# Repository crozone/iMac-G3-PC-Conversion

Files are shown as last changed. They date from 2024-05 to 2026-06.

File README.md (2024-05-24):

# iMac G3 - Gaming PC Conversion

Parts and instructions to convert an iMac G3 into a powerful, modern gaming PC.

* AMD Ryzen 5900X
* 32GB 3600 RAM
* ASUS ROG Strix X570-I
* NVIDIA 3080 (ASUS TUF OC)
* 750W Corsair PSU
* Custom water loop with D5 pump and 200x200mm radiator

## About

This is a project to convert a year ~2000 Apple iMac G3 DV (slot load, Graphite) computer into a fully fledged gaming PC, to serve as a portable LAN box and VR machine.

The donor iMac was broken and completely missing the actual compute unit, so no working iMacs were harmed in the making of this monstrosity.

This concept certainly isn't new, but I'm hoping to set this project apart by reducing the amount of destructive case modifications, and packing in significantly more power, hopefully without melting everything.

The project is still in-progress, but should eventually become an instructional kit for reproducing the mod.

## Project Status

### TODO

* Final laser cut parts for radiator mounting
* Additional brackets for case reinforcements
* Fan shroud to direct air through rear vent
* Additional fan mounts
* Slot loading BD drive bracket
* Case front panel wiring
* Side panel for IO extensions
* Final assembly
* Full documentation of all chassis modifications, third party parts, part locations, and assembly instructions

### What's complete

* All parts mounted in their final locations
* Custom water loop is complete and pressure tested (0.5 bar / 15 mins)
* PSU is patched to 240V plug on case (original location)
* PSU is wired to mobo, GPU, water pump and display
* UV LEDs placed and wired up to 12V RGB motherboard header
* Water loop filled and tested (small leak in QD fitting but otherwise all good)
* First bootup successful. BIOS configured, Windows 10 installed.
* Stress tested with UNIGINE Heaven benchmark, Prime95. Water loop appears to have plenty of thermal capacity, even at ~500W draw from CPU + GPU.

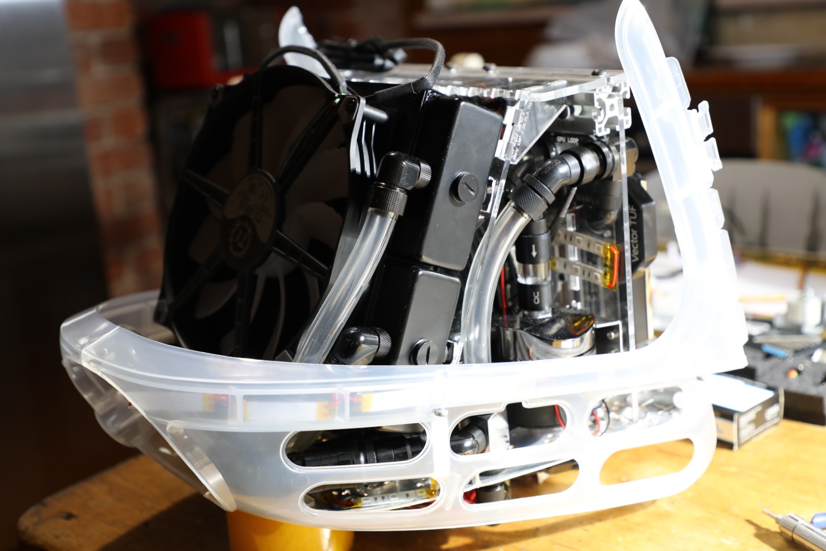
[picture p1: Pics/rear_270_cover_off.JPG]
Rear 270 deg disassembled view


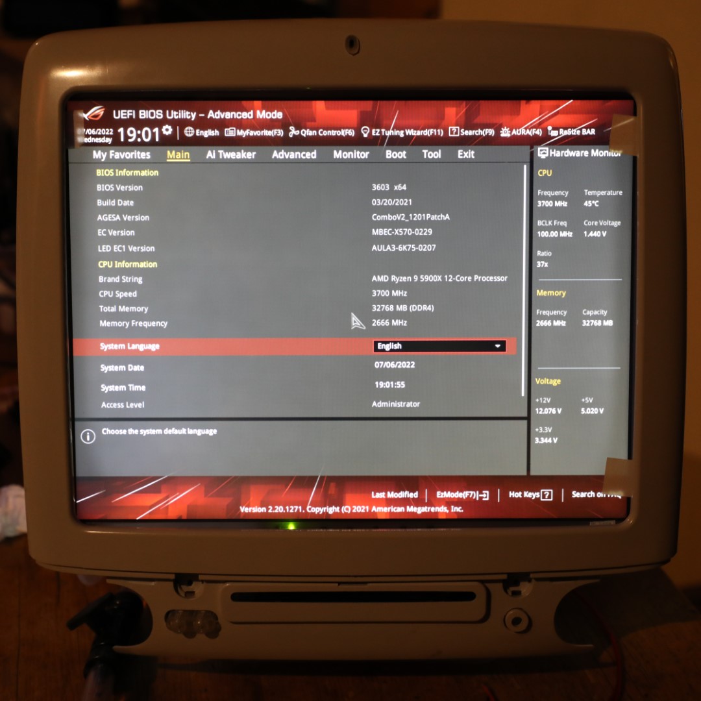
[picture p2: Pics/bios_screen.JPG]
BIOS screen


### Previous similar projects

Recently I discovered another iMac casemod project \([hackaday](https://hackaday.io/project/160719-imac-g3-casemod), [github repo here](https://github.com/Diepzeevogel/iMac-G3-replacement-parts)\). This includes many similar ideas, although the mounting locations are very different. None of the parts are directly usable but provide some good hints for layout.

## Overview of replacement components

### Display

HYDIS HV150UX2-100. It is a 15" LCD LVDS laptop display, that is UXGA (1600x1200), 4:3, and LED backlit. It's a slightly more expensive upgrade to the HV150UX1, which is CCFL backlit. 

The screen is almost a perfect fit for the iMac G3 stock display bezel, except the corners are slightly cut off by the curved edges. However, it's pretty close, and at this size and resolution I have not found a better display for the project, especially since this one has a display controller cheaply available on eBay.

It is held in via 4 3D printed nylon mounting brackets, which fit over the original CRT mounting holes:

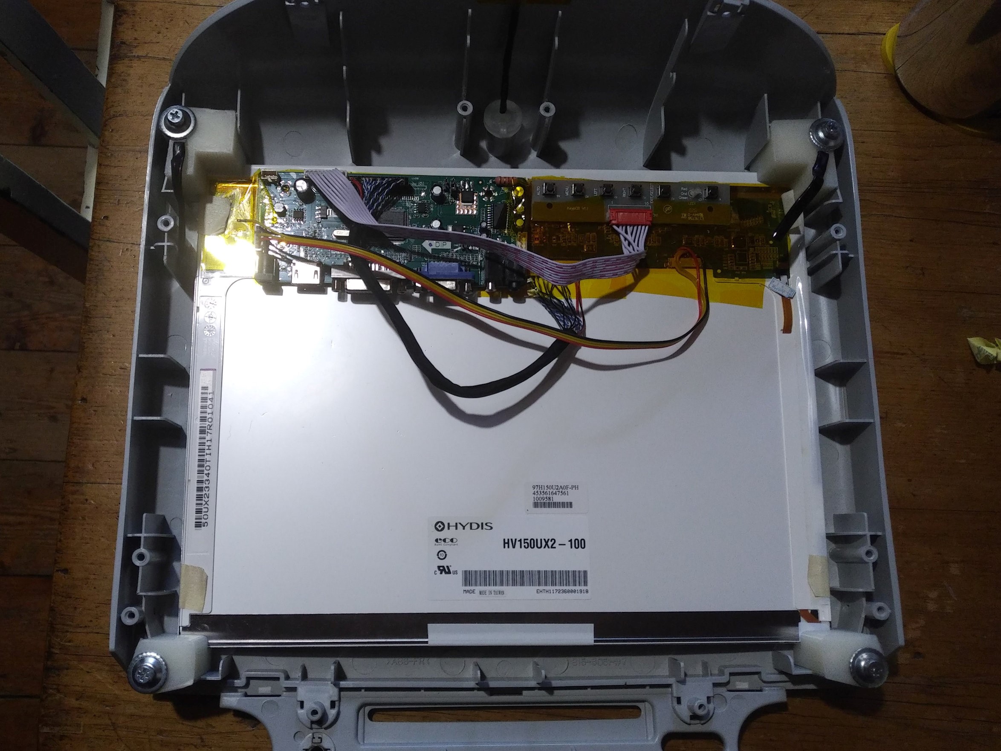
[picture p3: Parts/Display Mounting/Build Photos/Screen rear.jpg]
Display mounted rear


### Display adapter board

The HYDIS display is powered by a M.NT68676.2A.11486 LVDS controller board, which accepts HDMI and 12V power and outputs the display LVDS signal and backlight control.

The M.NT68676.2A.11486 is readily available on eBay as a drop-in controller for the HV150UX1, however it has to be slightly modified to work with the HV150UX2. Mainly, the LVDS connector has to be rewired, and the high voltage backlight driver removed. The power and control wires that previously went to the backlight driver need to be attached to the LCD backlight driver on the HV150UX2 display. Pin 8 of the driver connector also needs to be tied to 5V, to keep the display at maximum brightness, as it appears that the driver board does not set the voltage of this pin correctly.

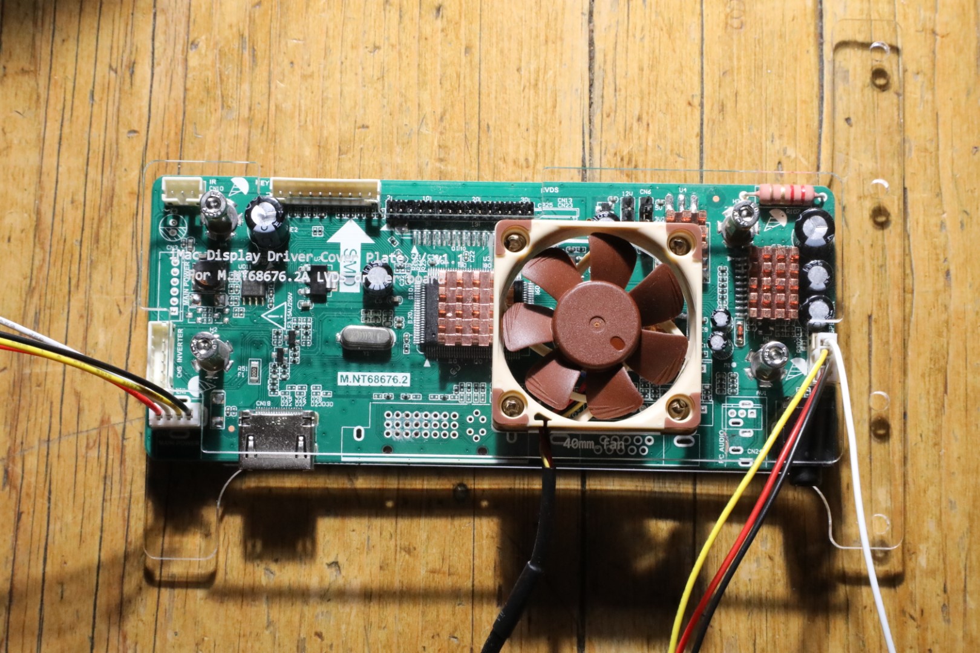
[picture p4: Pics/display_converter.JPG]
Display adapter


### GPU

The GPU is an ASUS 3080 TUF with a EK-Quantum Vector TUF RTX 3080/3090 water block and matching backplate.

It is mounted directly behind the LCD display panel, wedged in-between the LCD and the motherboard. It is mounted to a PCIe riser bracket, which is bolted to the metal chassis baseplate. This allows for a 30cm+ GPU to be mounted across the iMac behind the screen, since it is the widest part of the body. It also leaves more space free towards the rear of the iMac, for a water cooling radiator and PSU.

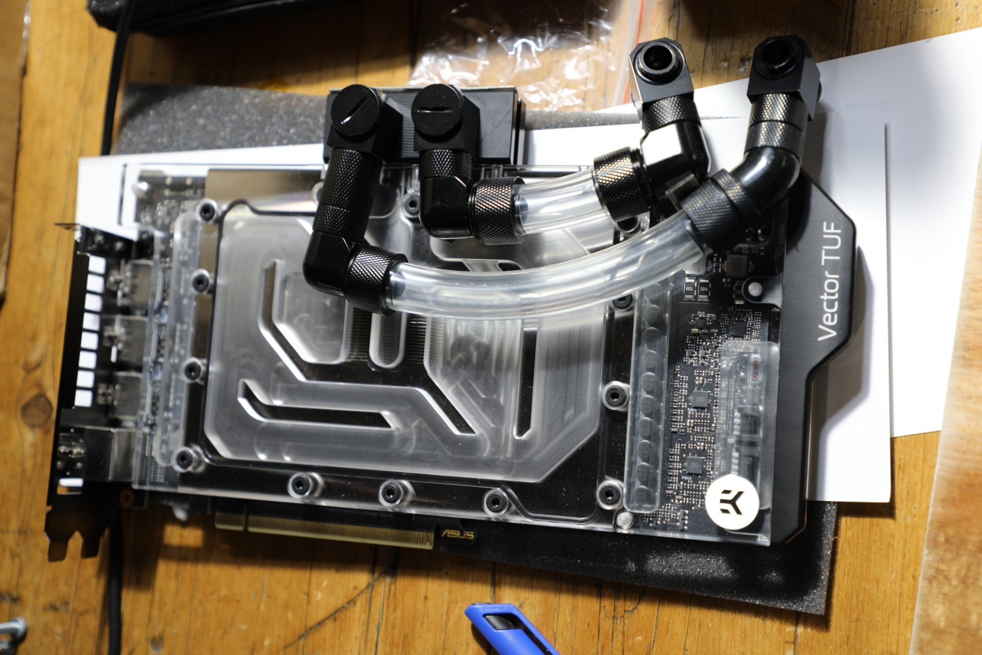
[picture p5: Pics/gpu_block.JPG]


The Koolance low profile right angle fittings (NZL-LXG2) were basically required in order to fit the piping behind the GPU. Thanks Koolance for manufacturing these magical fittings, they came in extremely clutch for this build.

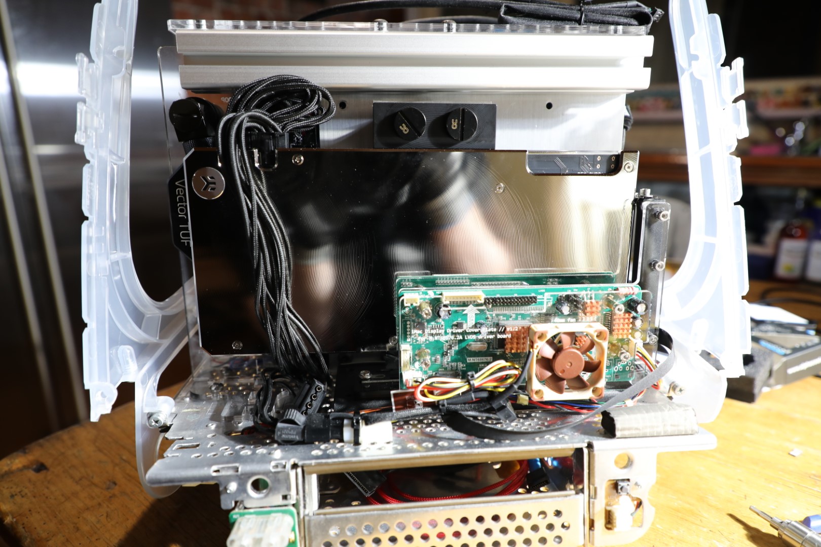
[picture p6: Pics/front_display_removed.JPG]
Display adapter mounted in front of GPU


### Case integration (Speakers, Microphone, Headphone jacks, Power button, Power Lamp)

The [qbancoffee imac_g3_ivad_board_init](https://github.com/qbancoffee/imac_g3_ivad_board_init) project contains a [J22 adapter PCB](https://github.com/qbancoffee/imac_g3_ivad_board_init/tree/master/schematics_and_pcbs/imac_g3_slot_loading_J22_adapter_board) which provides breakouts for the speakers, microphone, headphone jacks, power button, and power lamp. This means that the iMac wiring harnesses does not need to be modified and the original J22 connector can remain in-place.

* The case speakers are powered by a built-in amplifier included on the M.NT68676.2A.11486 display controller, i.e they become the "HDMI Audio" device.

* The microphone is wired into the rear panel mic. The J22 adapter board contains microphone circuitry.

* The power button and lamp are wired to the motherboard through the standard pins

* The headphone jacks are wired into the Front Panel Audio connector. The right jack is wired as a microphone input.

### Drive bay

The original slot-loading DVD drive is being replaced by a Panasonic UJ-265, which is a slot loading BDXL burner. It is a laptop drive that takes a slimline SATA+power cable, which can be easily converted to standard SATA+power with an adapter. It will be mounted with an acrylic bracket to correctly align it with the case slot.

### Motherboard

The motherboard form factor is miniITX. Space is incredibly limited and miniITX is the logical choice. Additionally, good quality microATX motherboards are few and far between, whereas miniITX boards are very popular and well supported.

The motherboard is mounted vertically behind the display using an aluminium backing plate and aluminium extrusion.

### CPU

AMD Ryzen 5900X with EK-Classic CPU water block.

The water block has the stock LEDs removed and replaced with a UV LED strip.

### Side ports

Side ports will need to be extended from the motherboard IO panel and GPU, and onto a 3D printed side panel mounted in the original iMac G3 IO panel location (TODO: Laser Cut Acrylic ports panel)

### PSU

A Corsair 750W SFX form factor PSU is mounted in a laser cut acrylic cage that hangs halfway through the metal baseplate of the iMac case.

The original rear power socket location is retained by reusing the original bracket with a shorter socket, and is extended to the PSU via patch cable.

### Cooling

The iMac G3 was originally designed for passive cooling, which makes active cooling a challenge. There are three main locations where air can be forced into and out of the case: The holes around the carry handle, the meshed access port on the underside, and the holes under the front speakers.

The CPU and GPU are both water cooled with a custom loop.

A large 200mm square radiator ([Alphacool NexXxoS XT45 Full Copper 200mm radiator](https://www.alphacool.com/shop/radiatoren/radiatoren-aktiv/180200-mm/25898/alphacool-nexxxos-xt45-full-copper-200mm-radiator)) and fan sits directly behind the rear carry handle vents.

The pump is a D5 Alphacool VPP655 with an Aquacomputer ULTITOP D5 MIRROR BLACK pump adapter. It is mounted vertically to an acrylic bracket, to the right of the motherboard.

TODO: The underside of the iMac can have smaller 60/70/80mm fans mounted to force air into the case.

### RGB Lights

~~No~~ Only a little RGB in this build... as a treat. Instead it's mostly Ultra-Violet 😎. The water cooling additive is Mayhems X1 concentrate UV green (or maybe red).

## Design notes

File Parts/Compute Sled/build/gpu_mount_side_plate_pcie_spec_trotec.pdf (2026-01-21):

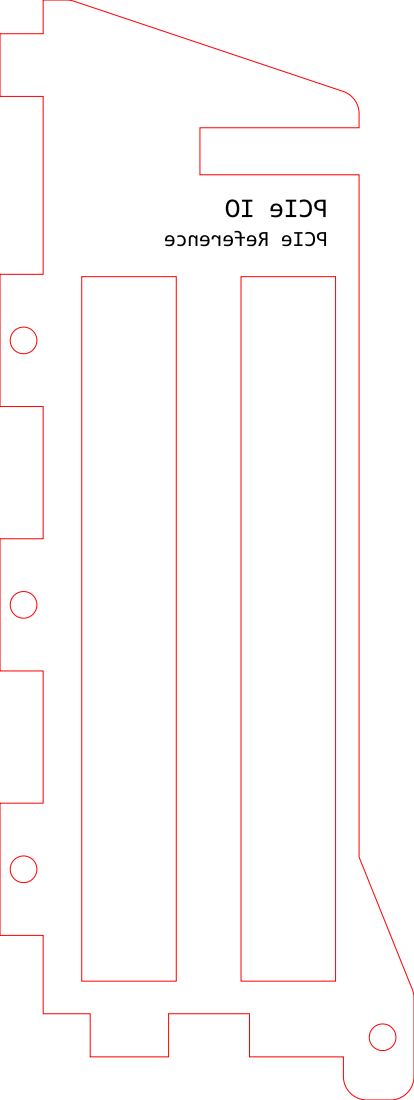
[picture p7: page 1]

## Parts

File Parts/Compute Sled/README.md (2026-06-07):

# Compute Sled

Frame to hold motherboard, water pump, and GPU.

## Fasteners
* 2x 6mm M3 screws [PCIe riser] // TODO CHECK
* 4x 6mm M3 screws [Pump bracket]
* 4x 6mm tall M3 male-female threaded standoffs [Motherboard mounting]
* 2x 6mm M4 screws [GPU card to bracket]
* 6x 12mm M4 screws [GPU bracket mounting]
* 12x 12mm M6 screws [10x for mounting plate brackets, 2x GPU support block]

## PCIe extension

ADT-Link K33UF-TU-FG

PCI-E 5.0 x16 to x16 turn 180 degree splint vertical extension cable

175-180mm length is ideal when used with 6mm thick acrylic.

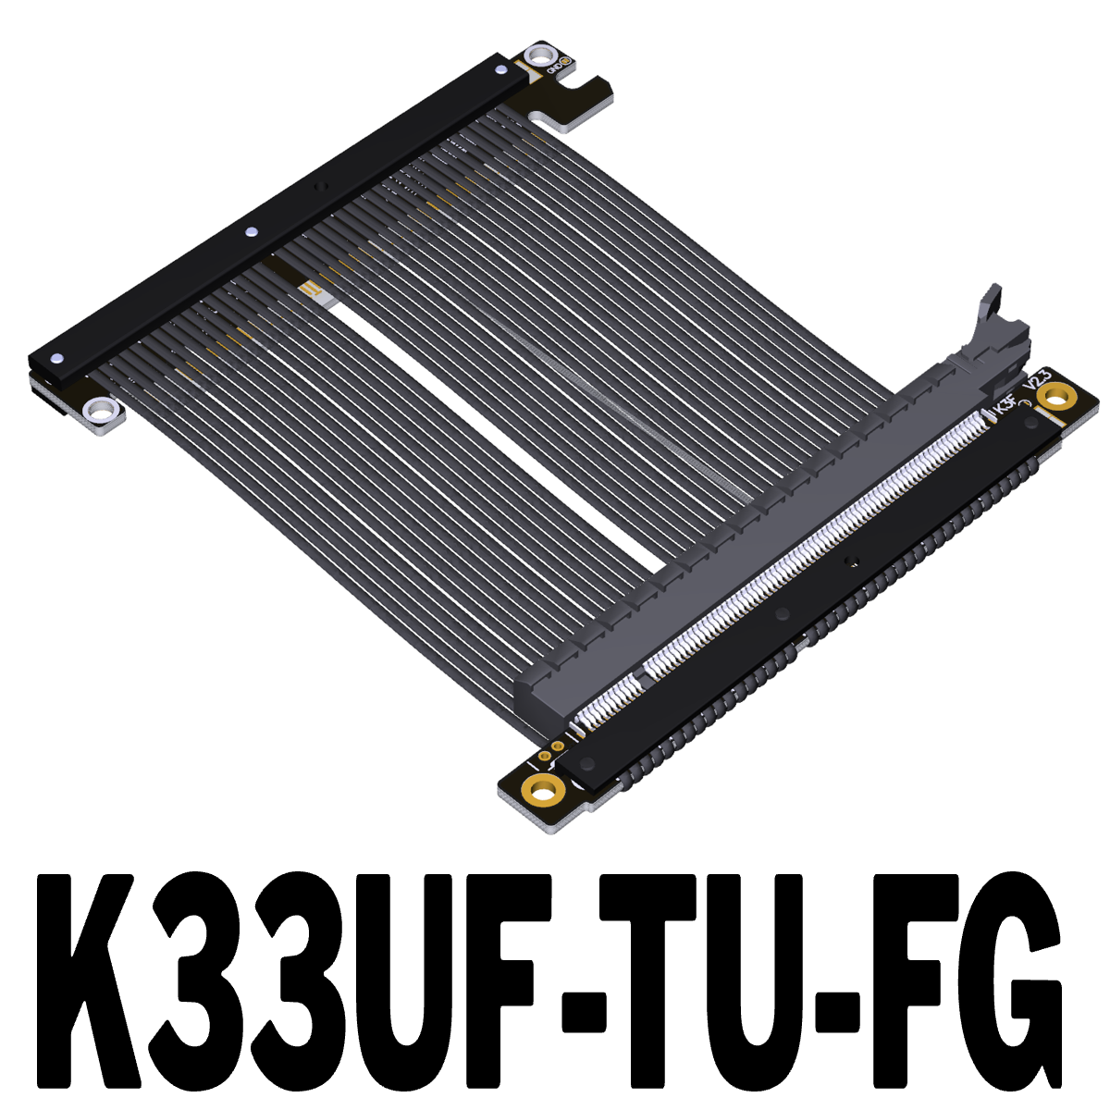
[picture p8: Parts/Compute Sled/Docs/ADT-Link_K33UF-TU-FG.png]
K33UF-TU-FG Render


## Pump

### Pump top with mounting bracket

Aquacomputer ULTITOP D5 MIRROR BLACK pump adapter for D5 pumps, G1/4

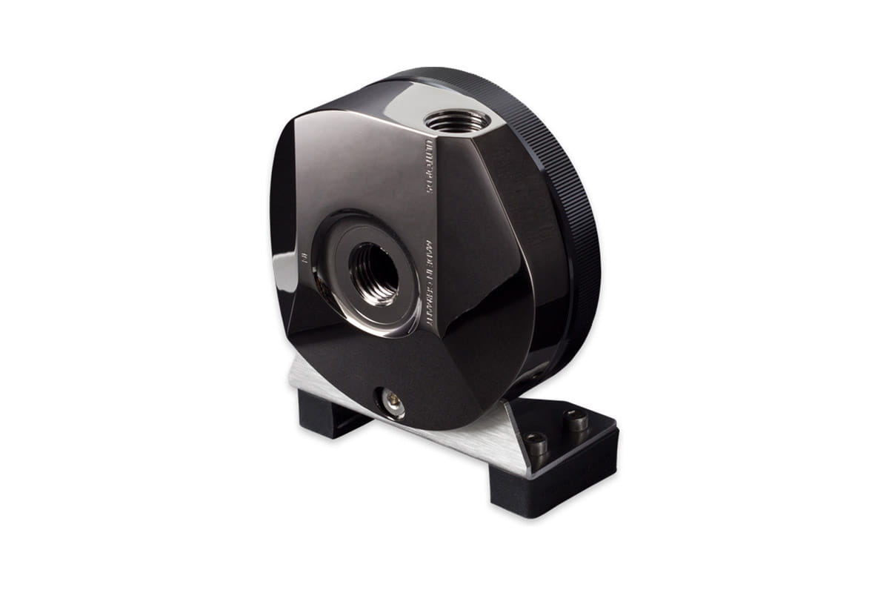
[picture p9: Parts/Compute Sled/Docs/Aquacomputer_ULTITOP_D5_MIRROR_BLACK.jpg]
ULTITOP_D5


### Pump

Alphacool VPP655

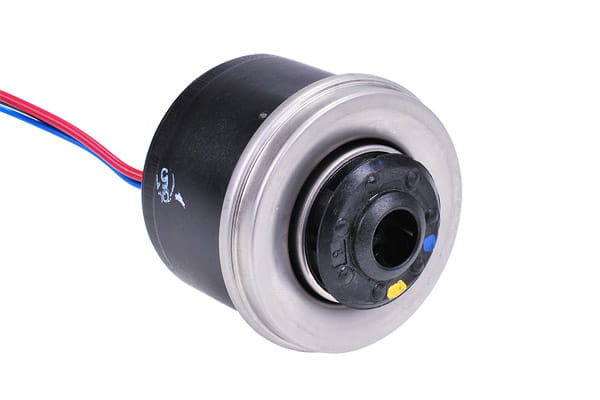
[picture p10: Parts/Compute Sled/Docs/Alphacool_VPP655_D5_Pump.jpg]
Alphacool VPP655


## GPU

Reference GPU is the RTX 5090 TUF with the Alphacool Core GeForce RTX 5090 TUF Gaming GPU Water Block.

Alphacool Core RTX 5090 TUF

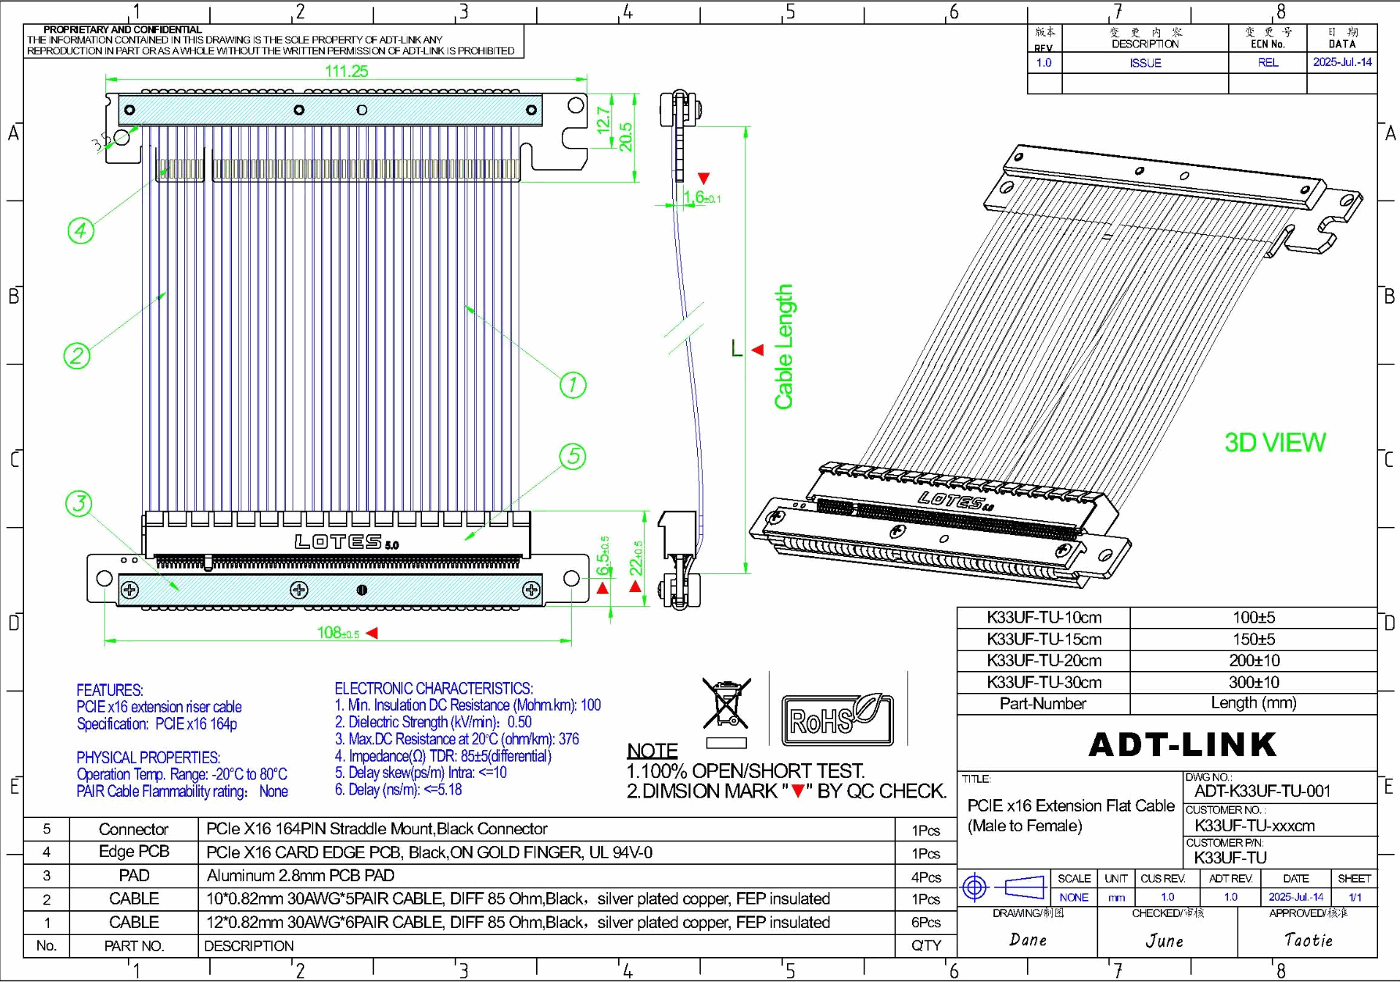
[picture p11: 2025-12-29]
Parts/Compute Sled/Docs/PCIe_riser_K33UF-TU.png

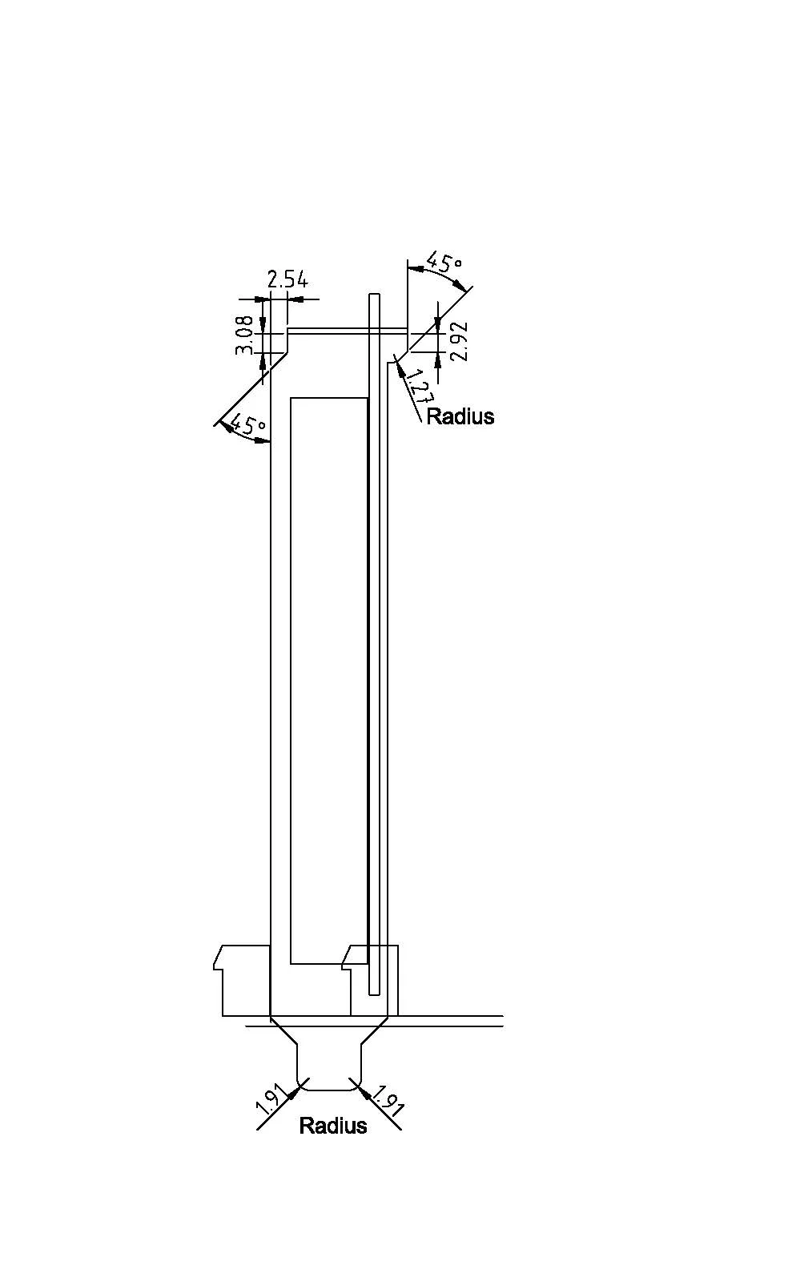
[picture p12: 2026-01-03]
Parts/Compute Sled/Docs/PCIe_Bracket_Face_Drawing_6.jpeg

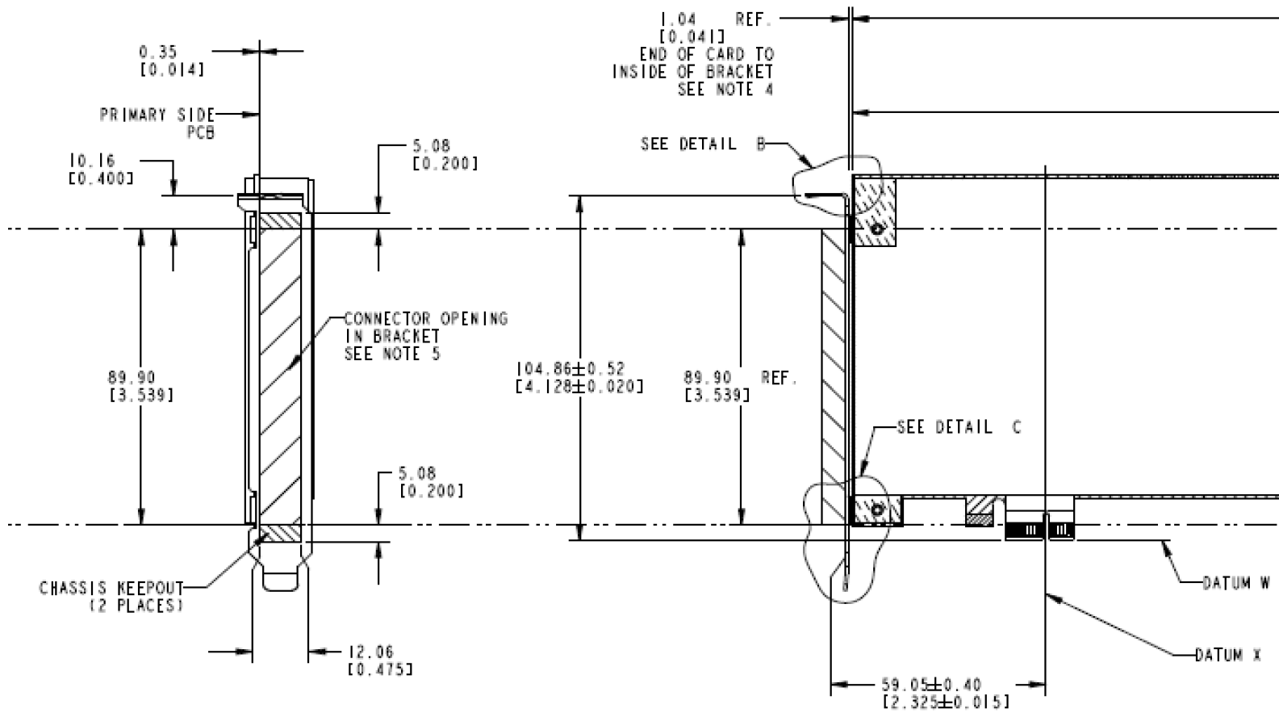
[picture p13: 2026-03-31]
Parts/Compute Sled/Docs/Bracket_drawing_3.png

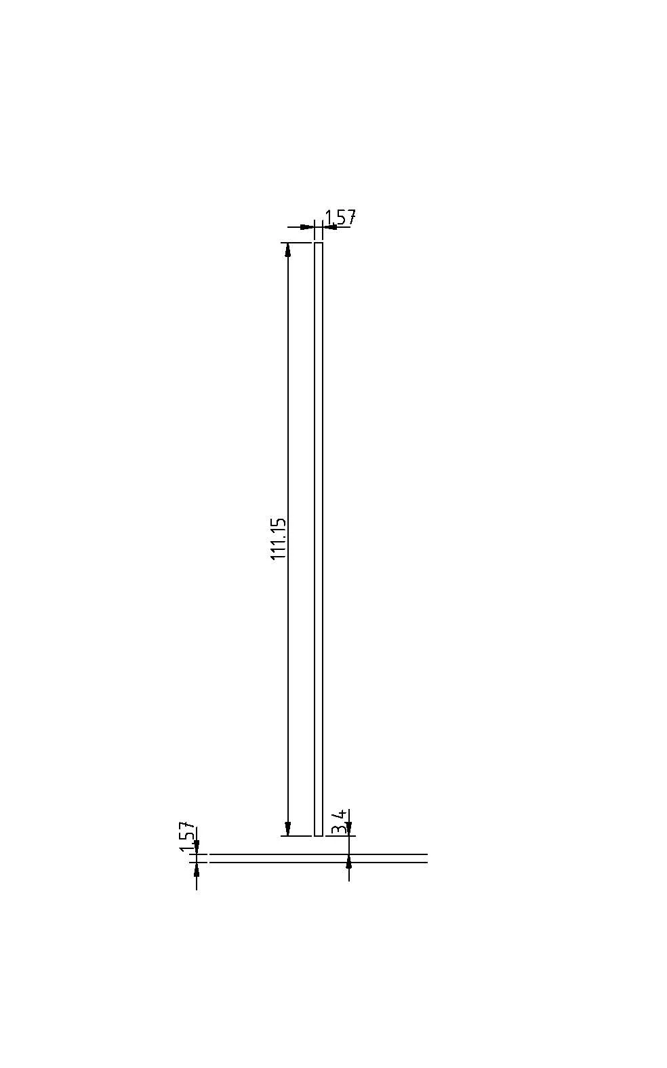
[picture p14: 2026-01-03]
Parts/Compute Sled/Docs/PCIe_Bracket_Face_Drawing_1.jpeg

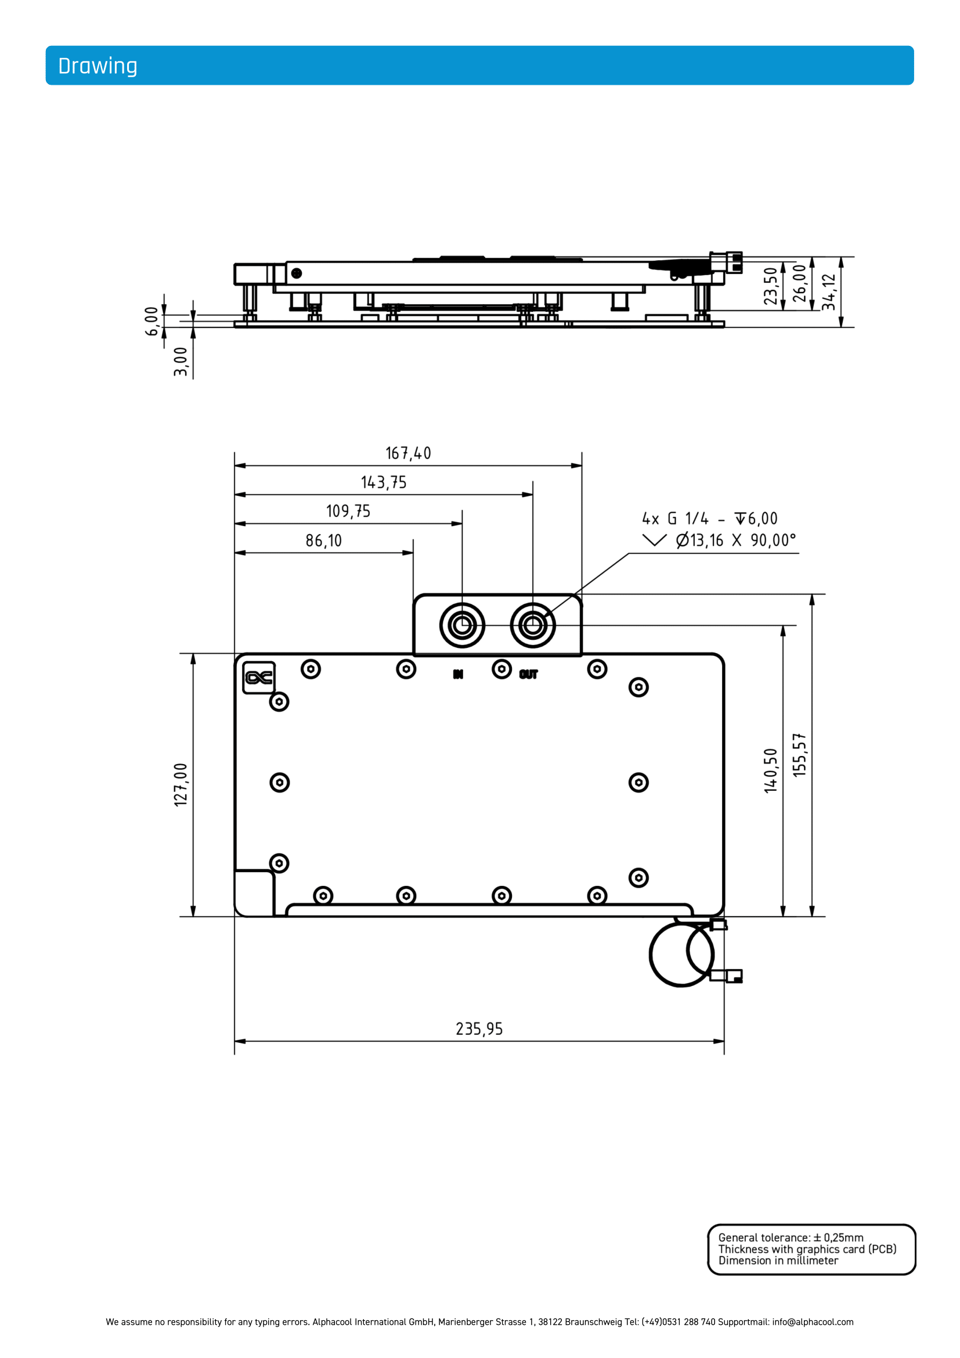
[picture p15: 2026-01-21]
Parts/Compute Sled/Docs/bo-1296458-ENG_10269_Alphacool_Core_Geforce_RTX_5090_TUF_Gaming_mit_Backplate_datasheet (1)-4.png

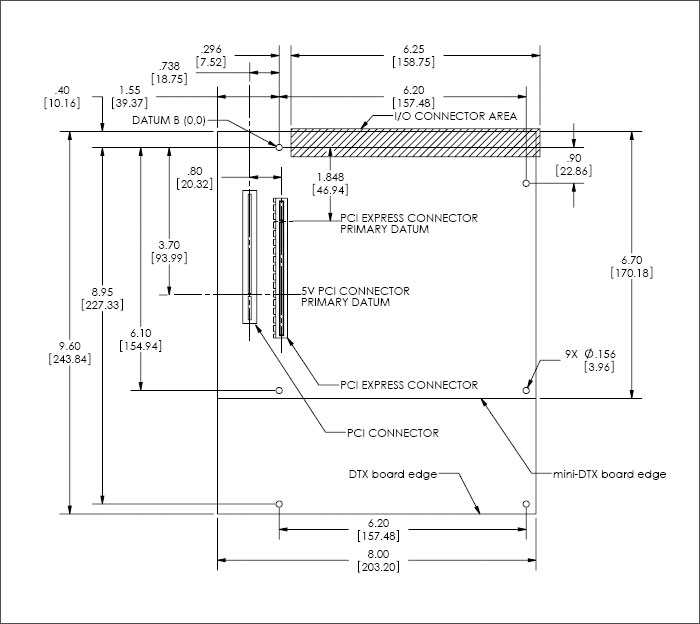
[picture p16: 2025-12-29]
Parts/Compute Sled/Docs/mobo_layout_minidtx.png

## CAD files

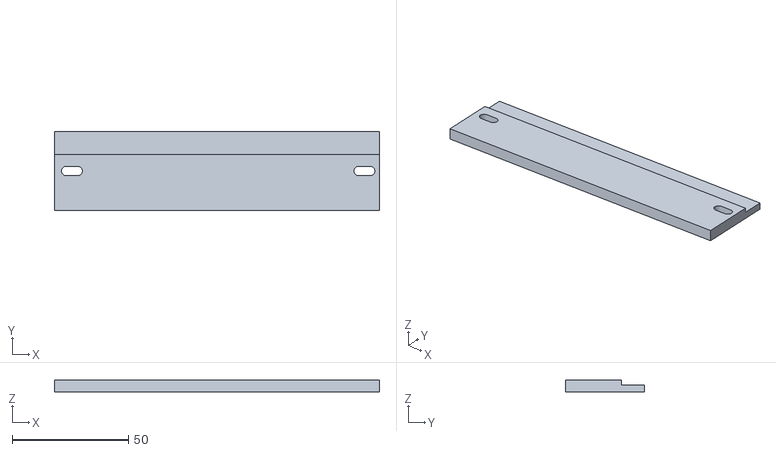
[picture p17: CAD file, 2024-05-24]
Mounting Brackets/GPU Mounting/STLs/PCIeSpacer.stl
140.0 x 34.0 x 5.00

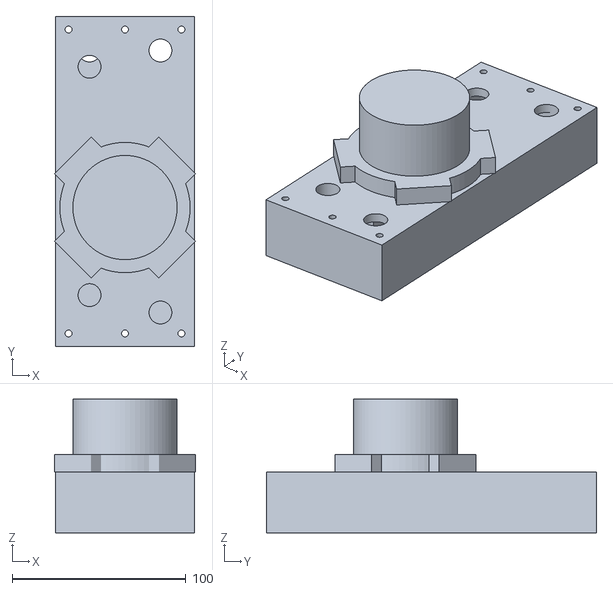
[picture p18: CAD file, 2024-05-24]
Mounting Brackets/Reservoir Mockup/reservoir_mock.stl
81.3 x 190.0 x 77.0

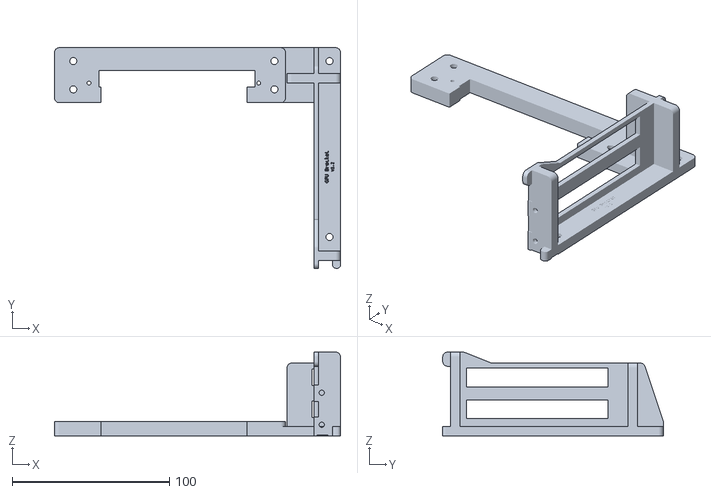
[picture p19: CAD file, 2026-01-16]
Parts/Compute Sled/build/gpu_mount.stl
182.0 x 140.4 x 53.3

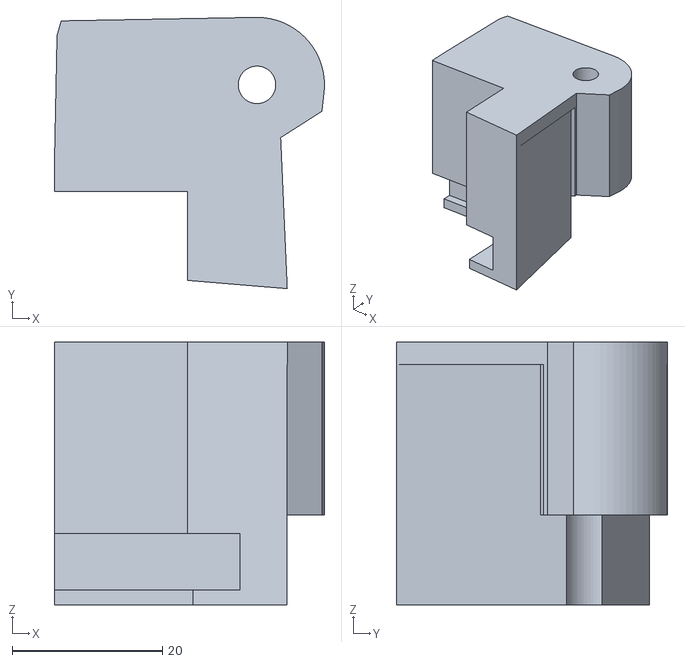
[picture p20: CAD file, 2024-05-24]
Parts/Display Mounting/STLs/display_mount_tr_3.stl
36.0 x 36.2 x 35.0

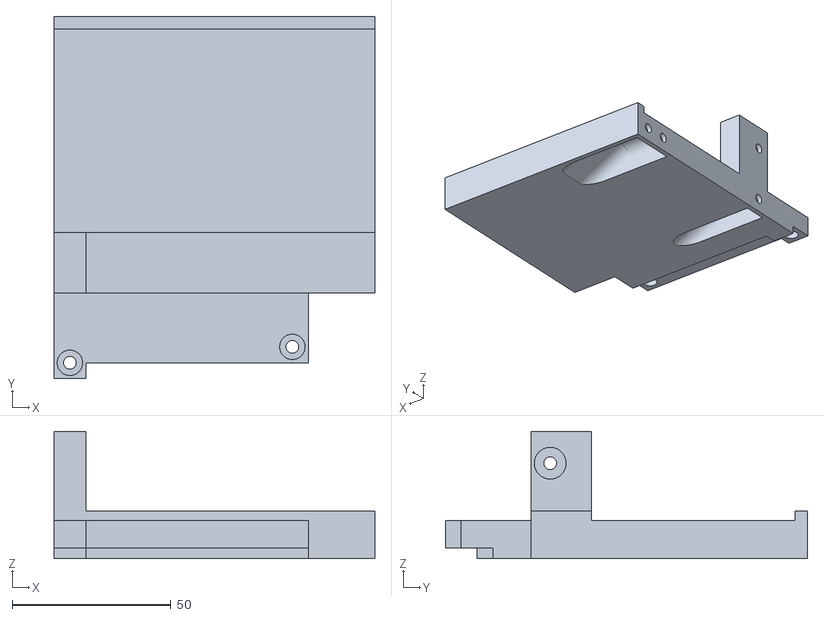
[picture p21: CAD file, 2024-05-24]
Parts/Display Mounting/STLs/Prototypes/PSU_mount_2.stl
101.0 x 114.0 x 40.0

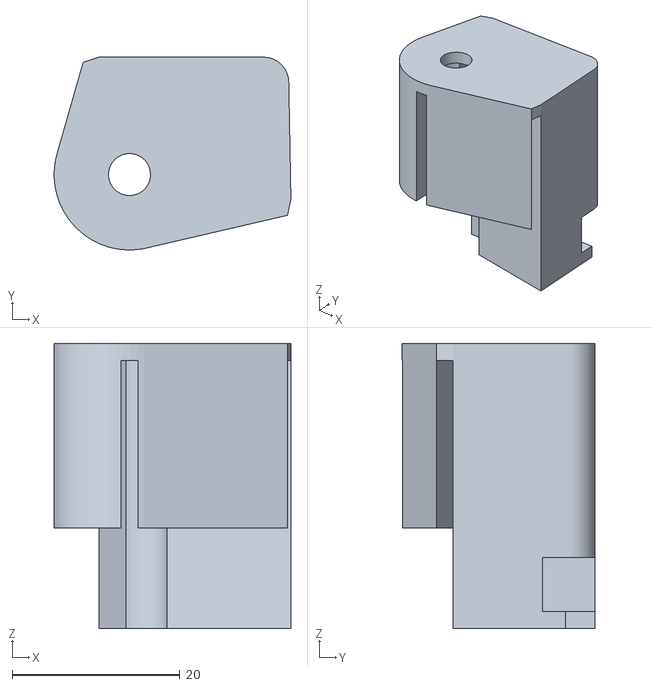
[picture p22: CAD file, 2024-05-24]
Parts/Display Mounting/STLs/display_mount_bl_3.stl
28.3 x 23.0 x 34.0

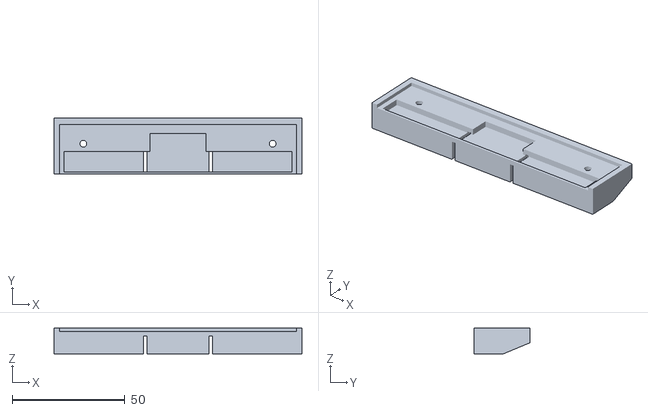
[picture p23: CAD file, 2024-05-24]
Parts/Display Mounting/STLs/Prototypes/display_control_mount_1.stl
110.0 x 25.0 x 11.5

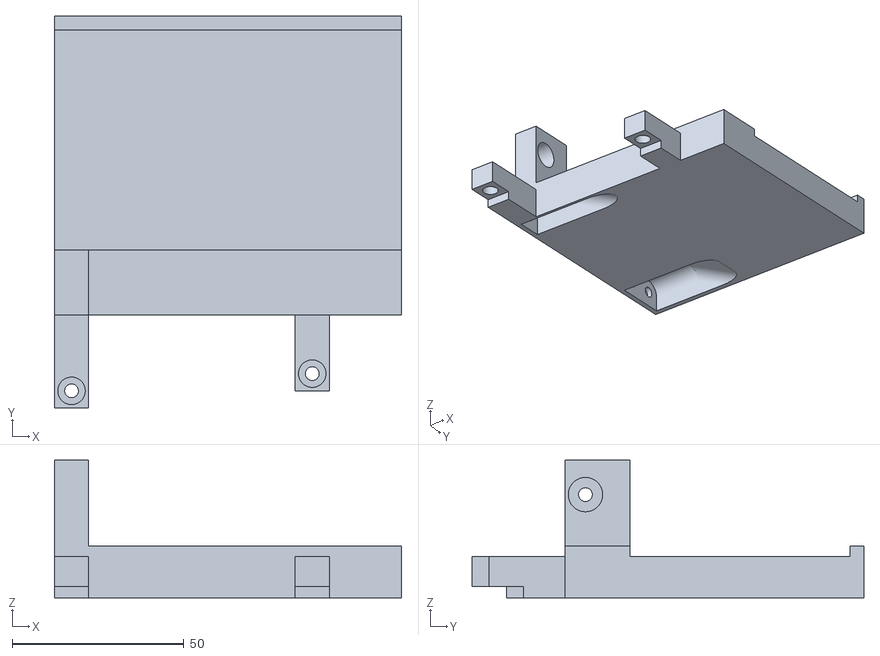
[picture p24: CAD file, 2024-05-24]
Parts/Display Mounting/STLs/Prototypes/PSU_mount_1.stl
101.0 x 114.0 x 40.0

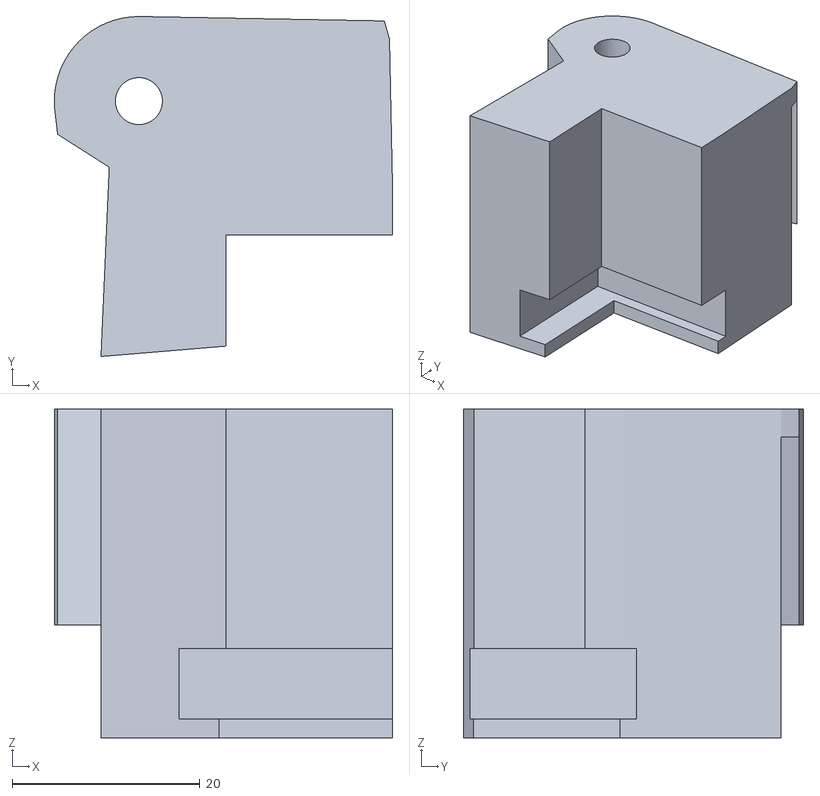
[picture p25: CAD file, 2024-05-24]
Parts/Display Mounting/STLs/display_mount_tl_3.stl
36.0 x 36.2 x 35.0

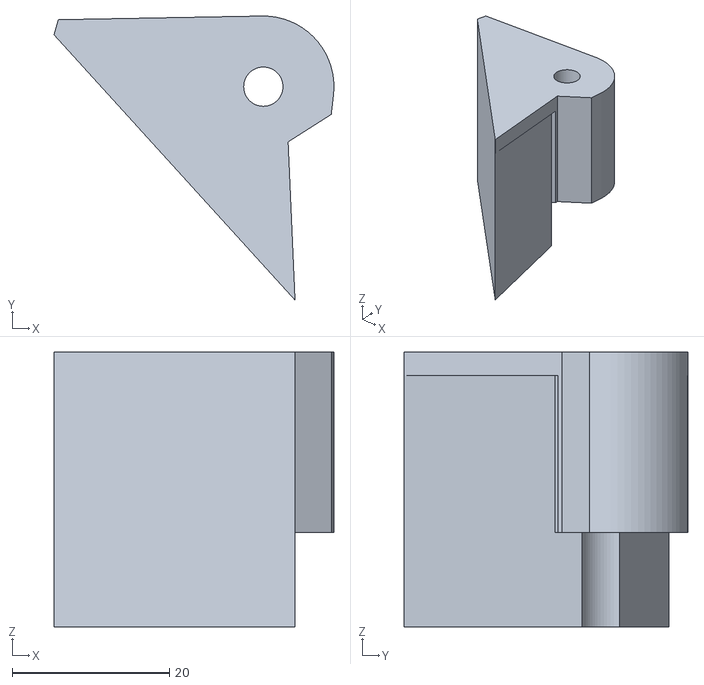
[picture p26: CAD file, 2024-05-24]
Parts/Display Mounting/STLs/Prototypes/display_mount_proto_7.stl
35.7 x 36.2 x 35.0

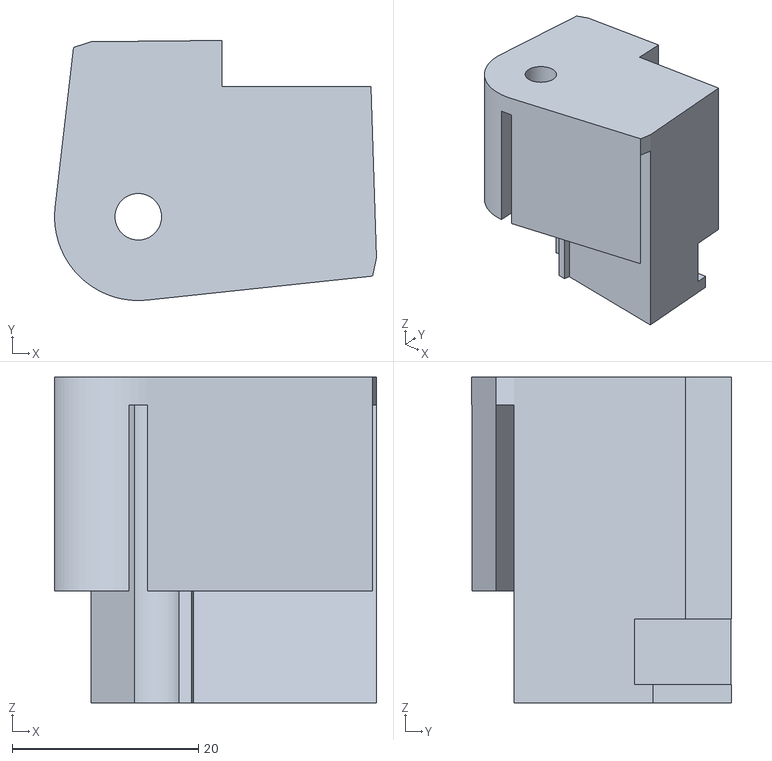
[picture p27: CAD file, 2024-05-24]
Parts/Display Mounting/STLs/Prototypes/display_mount_bl_1.stl
34.6 x 27.9 x 35.0

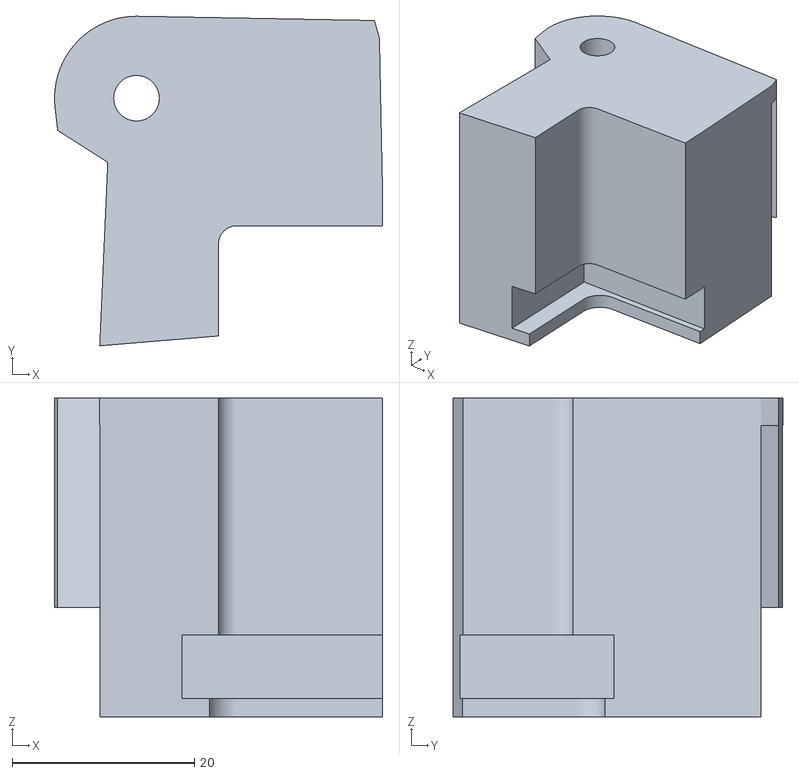
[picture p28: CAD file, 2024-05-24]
Parts/Display Mounting/STLs/Prototypes/display_mount_tl_1.stl
36.0 x 36.2 x 35.0

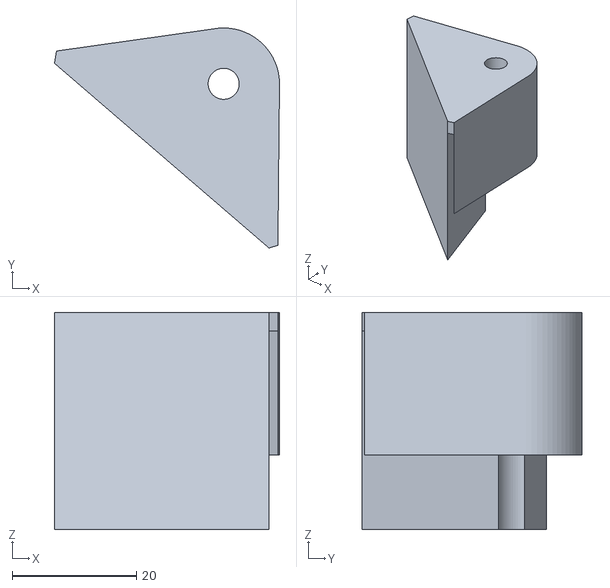
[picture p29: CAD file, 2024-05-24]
Parts/Display Mounting/STLs/Prototypes/display_mount_proto_2.stl
36.3 x 35.5 x 35.0

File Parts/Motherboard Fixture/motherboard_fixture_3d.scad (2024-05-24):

// 3D model representing the motherboard fixture.
// This includes the motherboard mounting bracket, extrusion, and motherboard itself.

$fn=256;

extrusion_width = 30;

// TODO: Accurate measurement
mobo_offset = -20;

mobo_plate_thickness = 3;


module motherboard_mount_3d() {
    module top_extrusion_bar() {
        cube([270, extrusion_width, extrusion_width], center = true);
    }

    module bottom_extrusion_bar() {
        cube([200, extrusion_width, extrusion_width], center = true);
    }

    module mobo_plate() {
        linear_extrude(height = mobo_plate_thickness) {
            square([200, 230], center = true);
        }
    }

    module pcie_cutout() {
        // TODO: Accurate measurement
        cube([100, extrusion_width * 2, extrusion_width + 0.5], center = true);
    }

    difference() {
        union() {
            translate([0, -extrusion_width / 2, 230])
            translate([0, 0, -extrusion_width / 2])
            top_extrusion_bar();

            translate([0, 3, 230 / 2])
            rotate([90, 0, 0])
            mobo_plate();

            translate([0, extrusion_width / 2 + mobo_plate_thickness, extrusion_width / 2])
            bottom_extrusion_bar();
        }

        translate([0, extrusion_width / 2 + mobo_plate_thickness, extrusion_width / 2])
        #pcie_cutout();
    }
}

module motherboard_exclusion_zone() {
    exclusion_height = 45;

    translate([0, 0, exclusion_height / 2])
    cube([200, 200, exclusion_height], center = true);
}

module motherboard_fixture_3d() {
    motherboard_mount_3d();

    %translate([0,mobo_plate_thickness + 5, 200 / 2 + extrusion_width])
    rotate([-90, 0, 0])
    motherboard_exclusion_zone();
}

motherboard_fixture_3d();

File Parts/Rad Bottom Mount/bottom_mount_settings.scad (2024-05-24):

include  <../Shared/shared_settings.scad>;

bottom_mount_version = "v1.2";
bottom_mount_height = 30;
bottom_mount_tab_length = 10; // length of tab.
bottom_mount_tab_width = bottom_mount_height;
bottom_connecting_tab_tab_height = material_thickness - 0.2;

bottom_mount_tab_positions = [
    [10, 0],
    [35 - material_thickness, 0],

    // [70, 0],
    // [95 - material_thickness, 0],

    //[125, 0],
    //[150 - material_thickness, 0],

    [140, 0],
    [165 - material_thickness, 0],
];

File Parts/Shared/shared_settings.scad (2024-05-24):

// Shared settings that need to be shared across most modules.

material_thickness = 4.5; // 4.5mm acrylic.

radiator_angle = 31;
radiator_bottom_mount_height_offset = 9.5;

text_font="Consolas:style=Regular";
text_size=16;

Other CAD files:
Parts/Display Mounting/STLs/display_mount_br_3.stl
Parts/Display Mounting/STLs/Prototypes/display_mount_bl_2.stl
Parts/Display Mounting/STLs/Prototypes/display_mount_tr_1.stl
Parts/Display Mounting/STLs/Prototypes/display_mount_br_1.stl
Parts/Display Mounting/STLs/Prototypes/display_mount_proto_8.stl
Mounting Brackets/Reservoir Mockup/reservoir_mock.scad
Legacy Parts/GPU Mounting/OpenSCAD/PCIeSpacer.scad
Legacy Parts/Reservoir Mockup/2Dshapes.scad
Legacy Parts/Reservoir Mockup/reservoir_mock.scad
Mounting Brackets/GPU Mounting/OpenSCAD/PCIeSpacer.scad
Mounting Brackets/OpenSCAD/PSU_mount.scad
Mounting Brackets/OpenSCAD/design.scad
Mounting Brackets/OpenSCAD/pci_mounting_rail.scad
Mounting Brackets/OpenSCAD/pci_riser_mount.scad
Parts/Compute Sled/compute_sled.scad
Parts/Compute Sled/gpu_mount.scad
Parts/Compute Sled/pcie_card_bracket.scad
Parts/Compute Sled/screw_hole_sizes.scad
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

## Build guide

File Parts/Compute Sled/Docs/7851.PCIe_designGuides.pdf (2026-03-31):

Copyright © 2004, PCI-SIG, All Rights Reserved | 1

## Board Design Guidelines for PCI Express™ Architecture

## Zale Schoenborn Co-Chair, PCI Express Electrical WG

PCI-SIG APAC Developers Conference | Copyright © 2004, PCI-SIG, All Rights Reserved | 2

## Agenda

ß Background
ß Layout considerations
ß System board requirements ß Add-in card designs
ß Signal validations
ß Summary

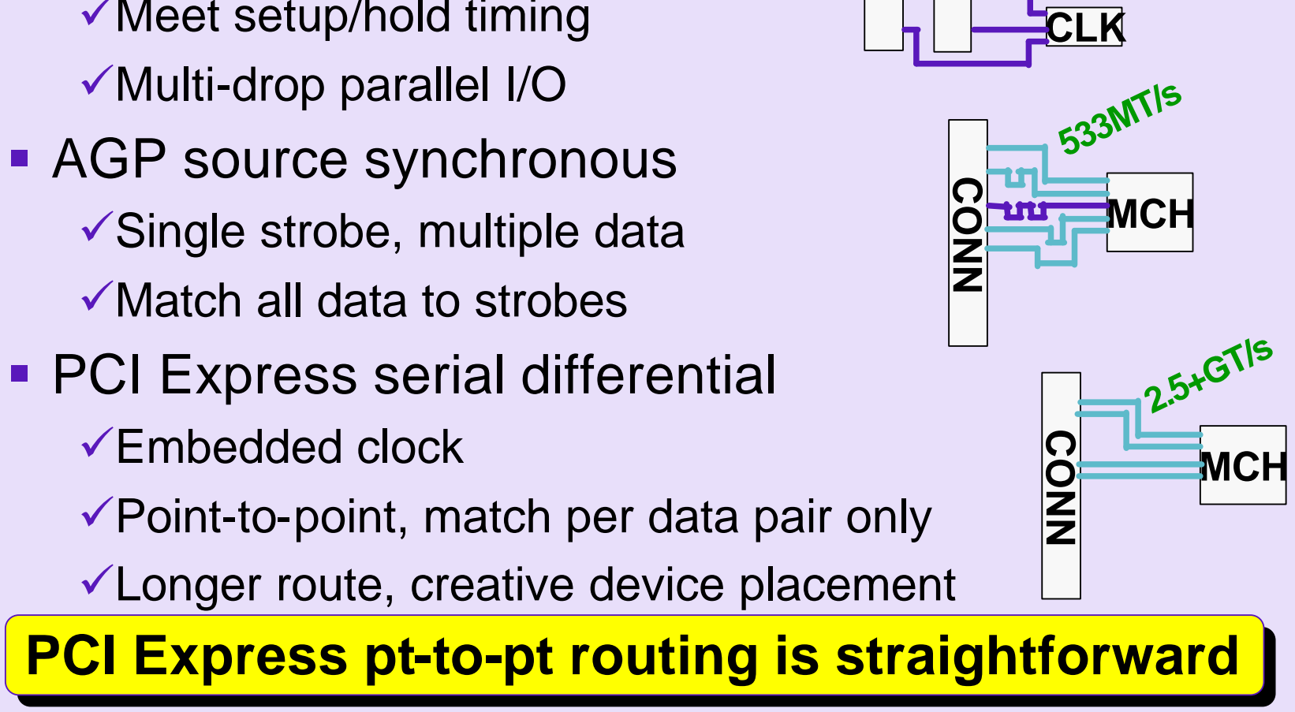
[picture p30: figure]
¸Multi-drop parallel I/O ß AGP source synchronous Şingle strobe, multiple data ¸Match all data to strobes ß PCI Express serial differential Ȩmbedded clock; Ļonger route, creative device placementCONN; MCH; CONN; CLK 533MT/s; PCI Express pt--; toto--pt routing is straightforward

PCI-SIG APAC Developers Conference | Copyright © 2004, PCI-SIG, All Rights Reserved | 3

## Bus Topology Evolution

ß PCI common clock
¸Meet setup/hold timing

¸Point-to-point, match per data pair only

CONN
MCH

CONN

133MT/s

Background

Serial Differential | Ḑiff pairs

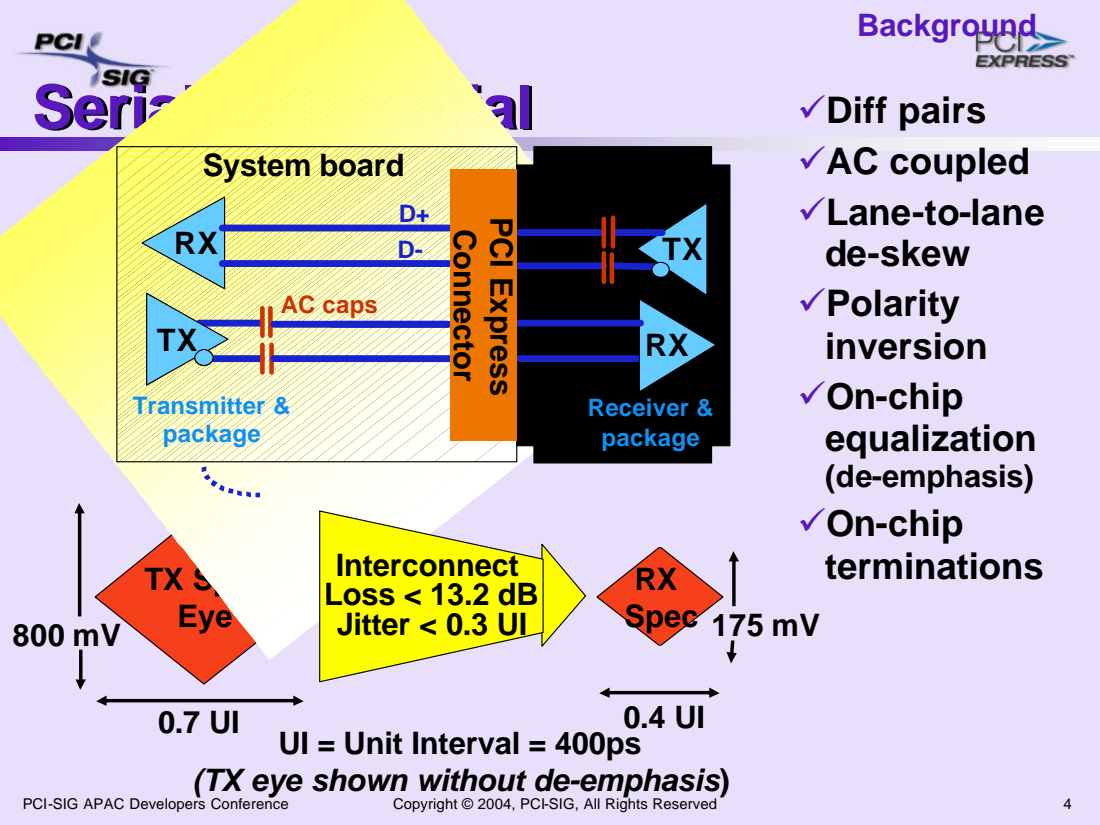
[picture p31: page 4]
PCI-SIG APAC Developers Conference; Copyright © 2004, PCI-SIG, All Rights Reserved; TX Spec Eye; RX Spec; System board; AC caps; Transmitter & package; Receiver & package; Interconnect Loss < 13.2 dB

Background
Jitter < 0.3 UI PCI Express Connector

Add-in card

¸AC coupled
Ļane-to-lane
de-skew
¸Polarity
inversion
¸On-chip
equalization
(de-emphasis)
terminations

(TX eye shown without de-emphasis)

UI = Unit Interval = 400ps

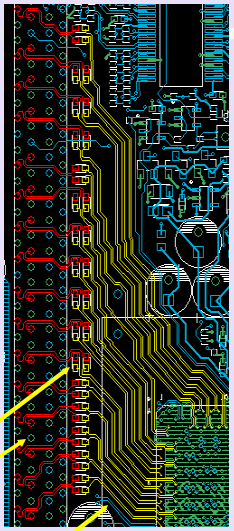
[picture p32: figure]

PCI-SIG APAC Developers Conference | Copyright © 2004, PCI-SIG, All Rights Reserved | 5

ß Trace length matching between pairs is not required
Ȩmbedded clock simplifies
routing rules
ß Longer motherboard traces
¸12+ inches possible
ß TX pairs usually route on top layer ¸AC coupling caps on TX traces on system board

Background

PCI Express x16 Connector
Trace Serpentines Not Required

AC Coupling Caps

## PCI Express Routing

## Interconnect Budget

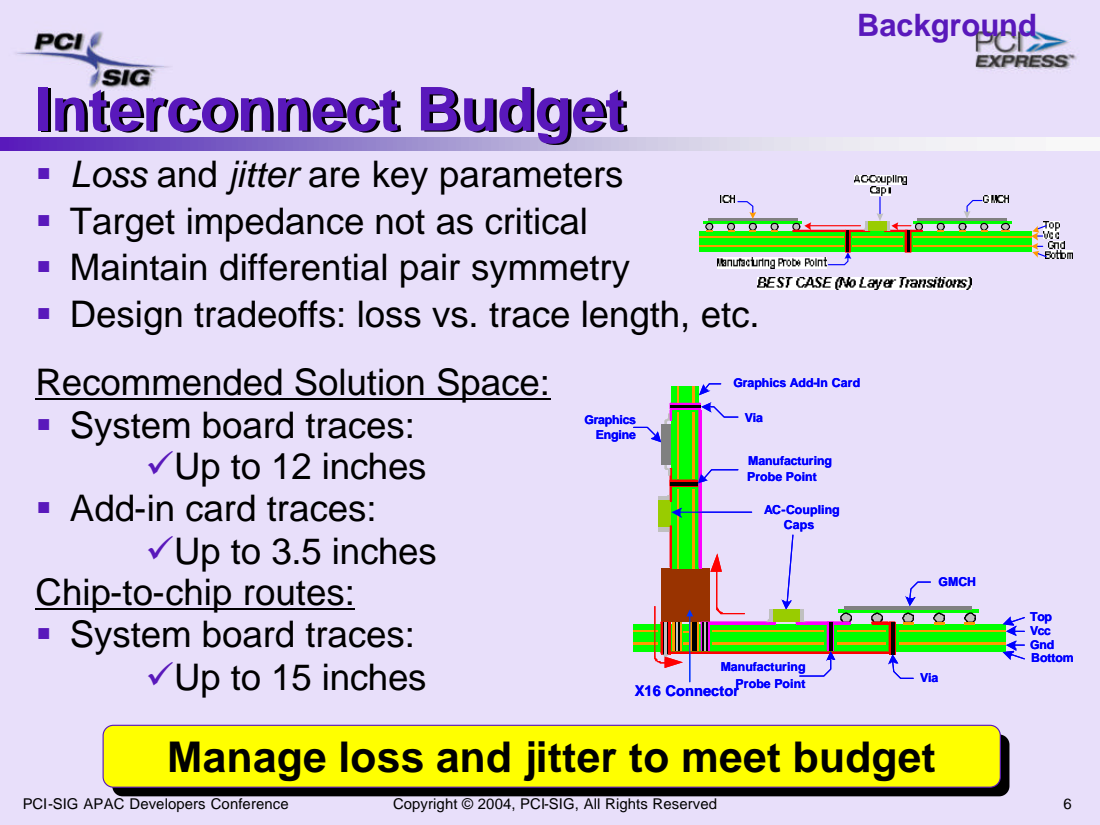
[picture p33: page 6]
PCI-SIG APAC Developers Conference; Copyright © 2004, PCI-SIG, All Rights Reserved; Background; AC-Coupling Caps; GMCH; Via; Manufacturing; Vcc Gnd; Top; Bottom; Graphics Engine; Manufacturing Probe Point

ß Loss and jitter are key parameters
ß Target impedance not as critical
ß Maintain differential pair symmetry
ß Design tradeoffs: loss vs. trace length, etc.
Recommended Solution Space:
ß System board traces:
¸Up to 12 inches
ß Add-in card traces:
¸Up to 3.5 inches
Chip-to-chip routes:
¸Up to 15 inches
Manage loss and jitter to meet budget

Graphics Add-In Card

Probe Point X16 Connector

## Stackup Design

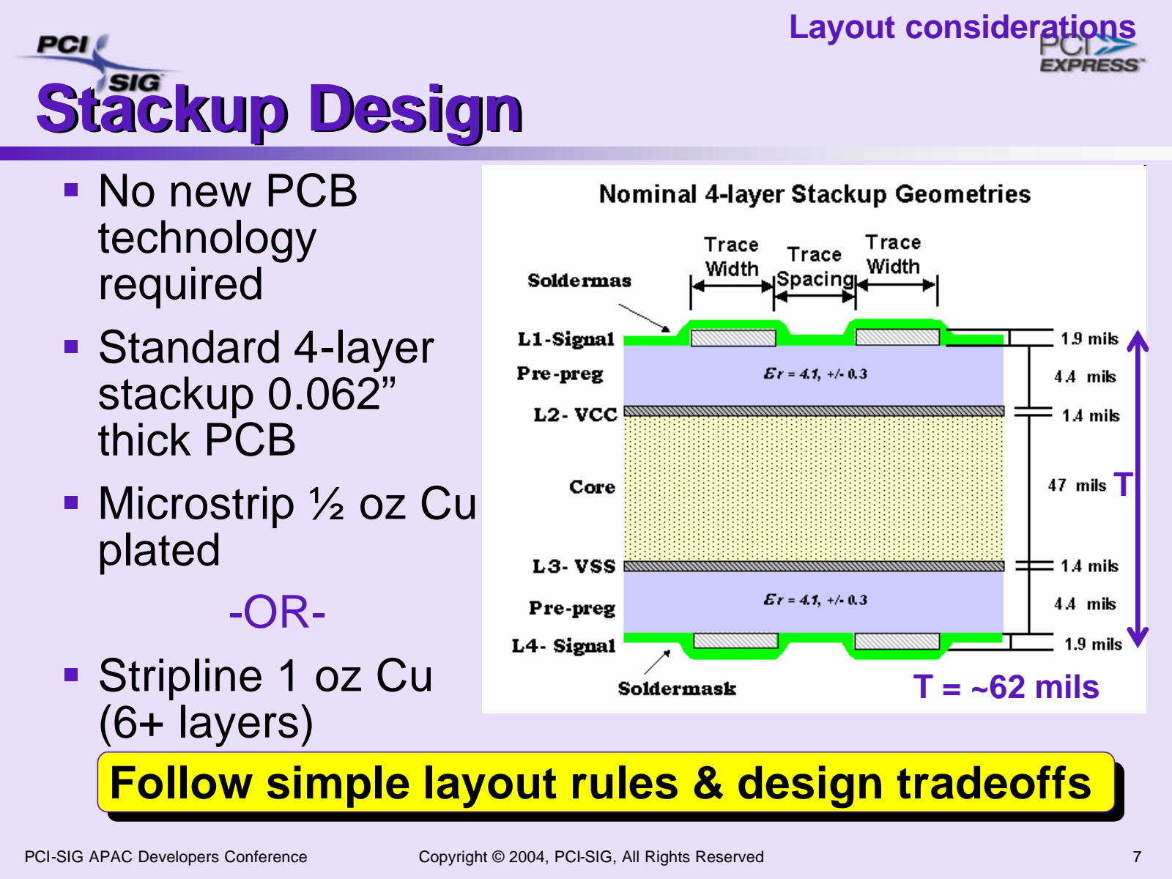
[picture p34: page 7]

PCI-SIG APAC Developers Conference | Copyright © 2004, PCI-SIG, All Rights Reserved | 7

ß No new PCB
technology
required
ß Standard 4-layer
stackup 0.062”
thick PCB
ß Microstrip ½ oz Cu
plated
-OR-ß Stripline 1 oz Cu
(6+ layers)
Follow simple layout rules & design tradeoffs

Layout considerations

T = ~62 mils

T

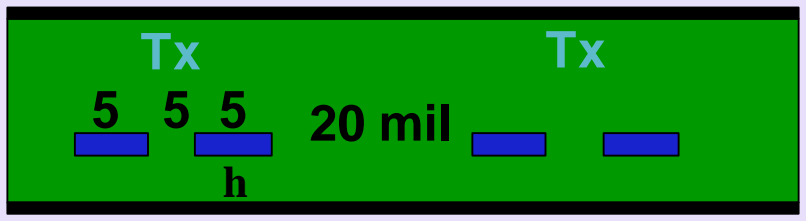
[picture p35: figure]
5 5 5 20 mil

PCI-SIG APAC Developers Conference | Copyright © 2004, PCI-SIG, All Rights Reserved | 8

ß Wide pair-to-pair spacing ⇒ minimize crosstalk ¸“Close” intra-pair spacing
ß Same geometry for interleaved/non-interleaved ß Example impedance targets:
Şingle-end Zo of 60 Ω ±15%
Ḑifferential Impedance of ~100 Ω ±20%

## Trace Geometry & Impedance

Layout considerations

Non-interleaved topology example

Interleaved topology example

Rx | Tx | Rx
Tx | Tx | Tx
h

### 20 mil 5 7 5

Microstrip

Stripline

Tx

Tx

w

w

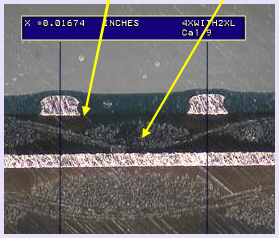
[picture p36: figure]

PCI-SIG APAC Developers Conference | Copyright © 2004, PCI-SIG, All Rights Reserved | 9

## FR4 Loss Considerations

ß Stackup: FR4 material
Ņarrow traces ⇒ loss ↑
Çopper roughness ⇒ loss ↑ Ḑielectrics with more resin material ⇒ loss ↑
ß Non-homogeneous dielectrics

Ļocalized Zo variation due to material weave ⇒ loss ↑
ß Wide differential impedance variation on μstrip traces Ȩtching and plating process ⇒

Resin Material

Glass Material

FR4 cross-section

Layout considerations

loss ↑

## Trace Length

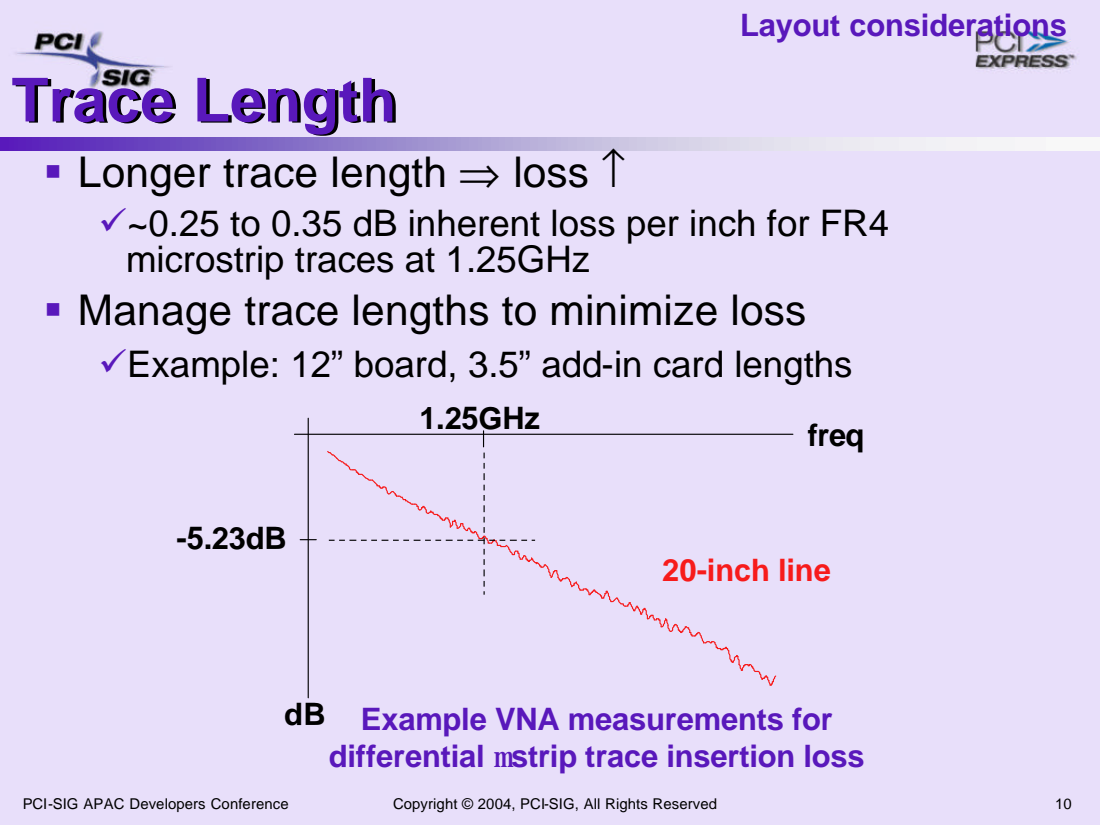
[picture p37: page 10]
PCI-SIG APAC Developers Conference; Copyright © 2004, PCI-SIG, All Rights Reserved; 1.25GHz; 20-inch line; freq; Layout considerations

ß Longer trace length ⇒ loss ↑
¸~0.25 to 0.35 dB inherent loss per inch for FR4
microstrip traces at 1.25GHz
ß Manage trace lengths to minimize loss
Ȩxample: 12” board, 3.5” add-in card lengths

Example VNA measurements for
differential mstrip trace insertion loss

## Trace Symmetry & Matching

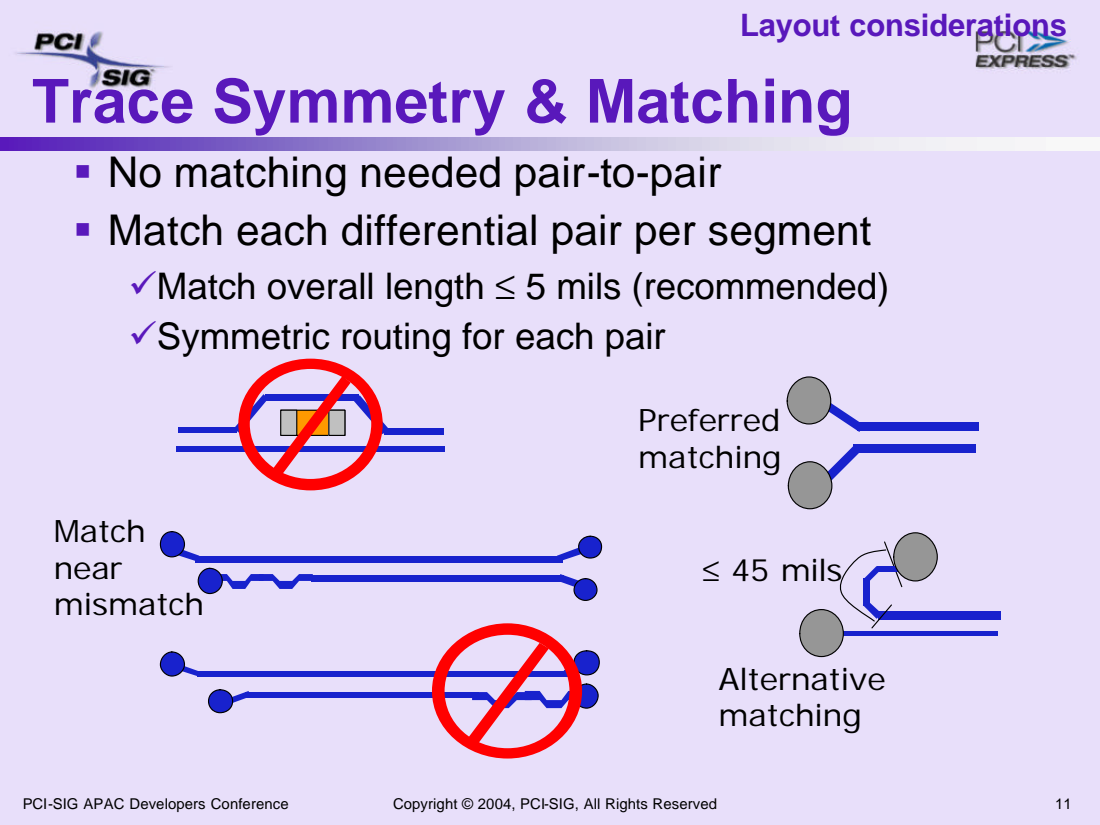
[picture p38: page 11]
PCI-SIG APAC Developers Conference; Copyright © 2004, PCI-SIG, All Rights Reserved; Layout considerations; Match near mismatch; Preferred matching; Alternative matching; ≤ 45 mils

ß No matching needed pair-to-pair
ß Match each differential pair per segment
¸Match overall length ≤ 5 mils (recommended)
Şymmetric routing for each pair

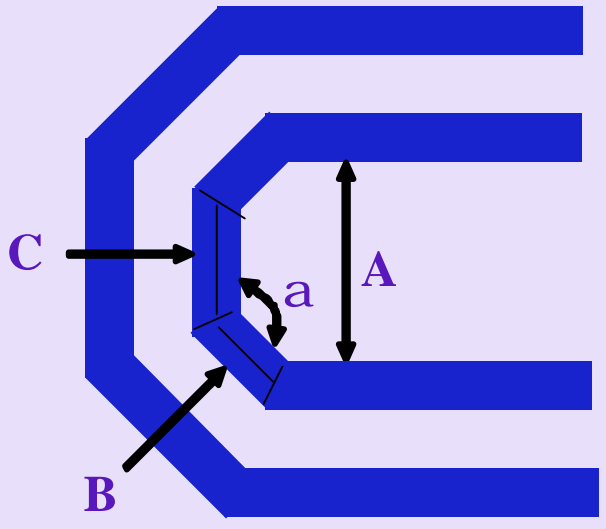
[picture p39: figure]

PCI-SIG APAC Developers Conference | Copyright © 2004, PCI-SIG, All Rights Reserved | 12

ß Avoid tight bends
Ņo 90° bends; impact to loss and jitter budgets
ß Keep angles >= 135° (a)
ß Maintain adequate air gap ¸ A >= 4x the trace width
ß Lengths of B, C >= 1.5x the width of the trace

ß Serpentines length is at least 3w for jog

## Bends and Small Serpentines

Layout considerations

S S1 < 2 S >3w

w

## Package Pin Field Breakout

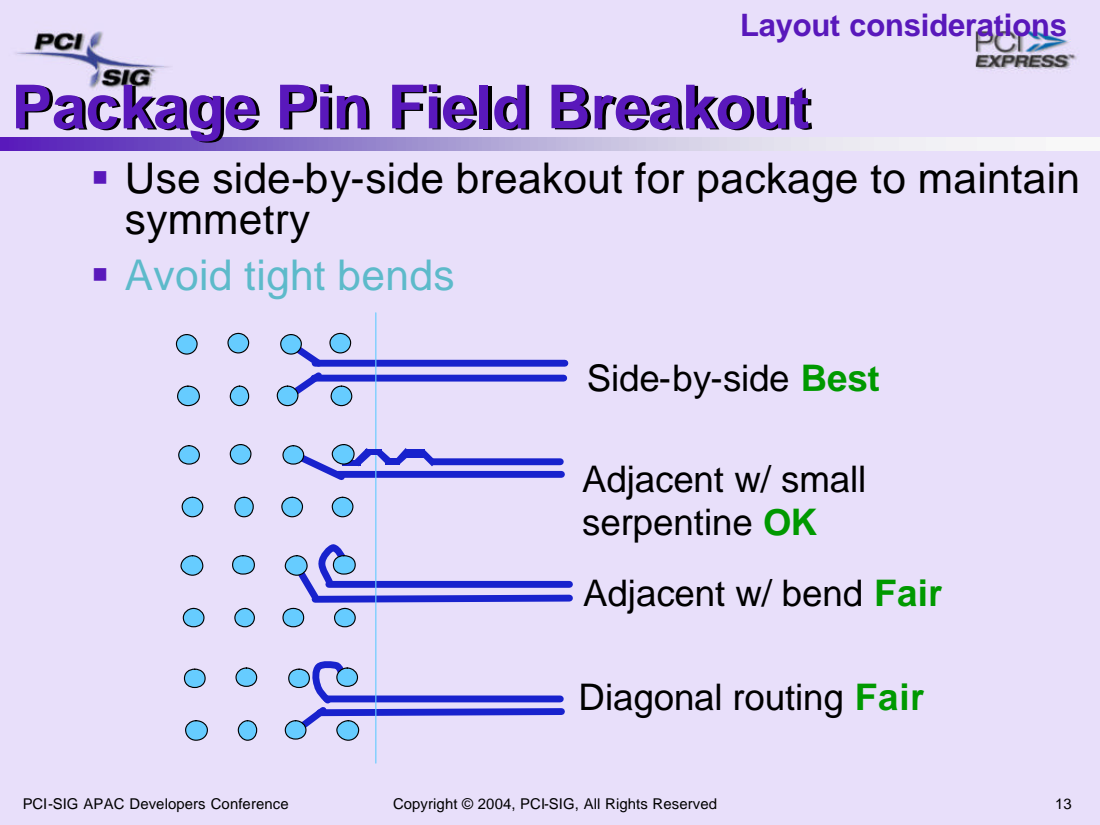
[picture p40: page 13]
PCI-SIG APAC Developers Conference; Copyright © 2004, PCI-SIG, All Rights Reserved; Layout considerations

ß Use side-by-side breakout for package to maintain
symmetry
ß Avoid tight bends

Side-by-side Best

Adjacent w/ small
serpentine OK
Adjacent w/ bend Fair

Diagonal routing Fair

## Reference Plane

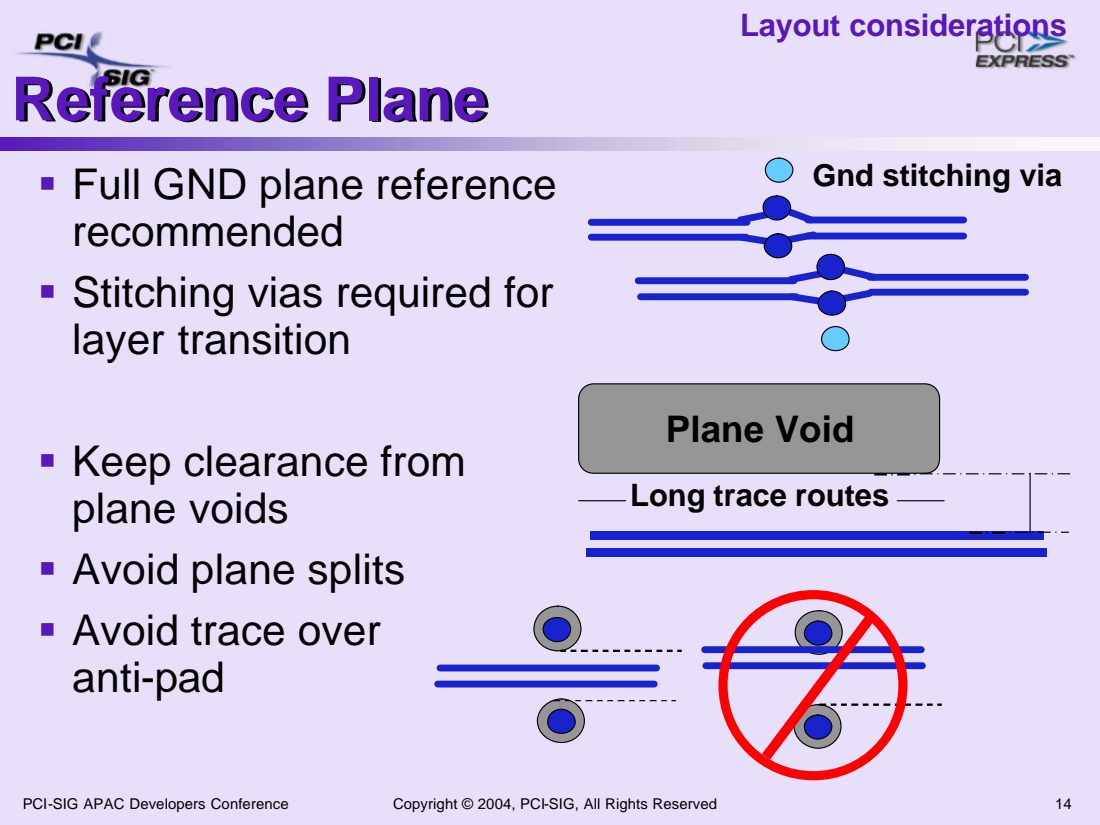
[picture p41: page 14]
PCI-SIG APAC Developers Conference; Copyright © 2004, PCI-SIG, All Rights Reserved; Layout considerations; Plane Void

ß Full GND plane reference
recommended
ß Stitching vias required for
layer transition

Gnd stitching via

ß Keep clearance from
plane voids
ß Avoid plane splits
ß Avoid trace over
anti-pad

Long trace routes

PCI-SIG APAC Developers Conference | Copyright © 2004, PCI-SIG, All Rights Reserved | 15

## AC Coupling Caps

ß Size: 0402 best, 0603 ok ß No 0805 size or C-packs
ß Symmetric placement best

ß Cap size: 0.1uF best
ß Same sizes for both D+/D-ß Cap location:
¸Along Tx pairs on system board ¸Along Tx pairs on add-in card

Layout considerations

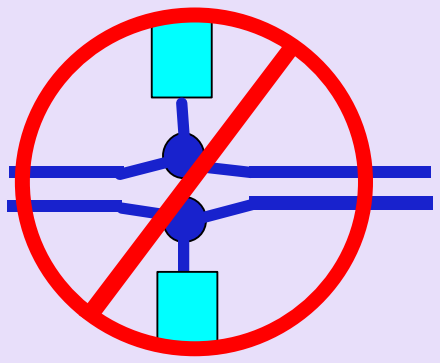
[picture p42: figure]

PCI-SIG APAC Developers Conference | Copyright © 2004, PCI-SIG, All Rights Reserved | 16

## Test Points & Vias

ß Minimize via usage
¸Up to 0.25 dB loss per via
¸Use via pad size ≤ 25 mil, hole size ≤ 14 mil; standard anti-pad size of 35 mil
ß Put test points or LAI pads in series (if used) Ņo stubs
¸Place symmetrically
¸Provide GND pads for single-ended probing
LAI pads

GND pads

Probe pads

Layout considerations

## Reference Clock

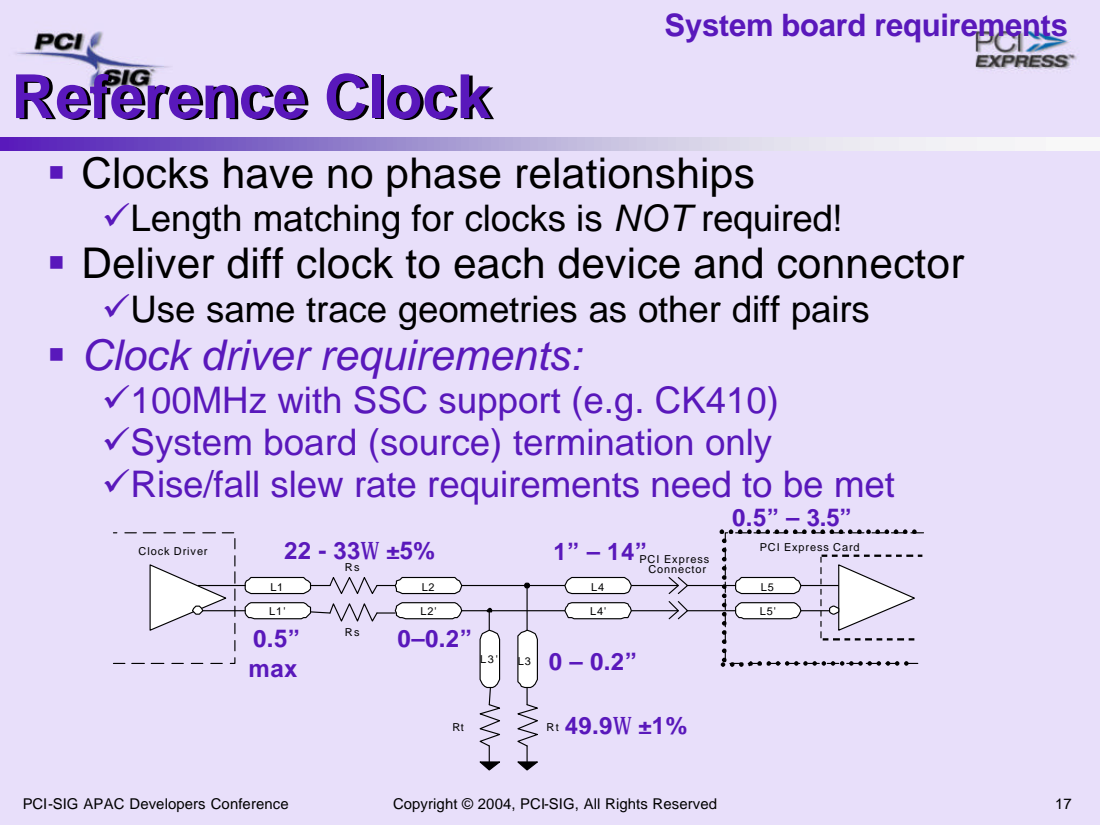
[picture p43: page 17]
PCI-SIG APAC Developers Conference; Copyright © 2004, PCI-SIG, All Rights Reserved; PCI Express Connector; Clock Driver; PCI Express Card; 0.5” max

System board requirements

ß Clocks have no phase relationships
Ļength matching for clocks is NOT required!
ß Deliver diff clock to each device and connector
¸Use same trace geometries as other diff pairs
ß Clock driver requirements:
¸100MHz with SSC support (e.g. CK410)
Şystem board (source) termination only
Ŗise/fall slew rate requirements need to be met

## Connector Layout

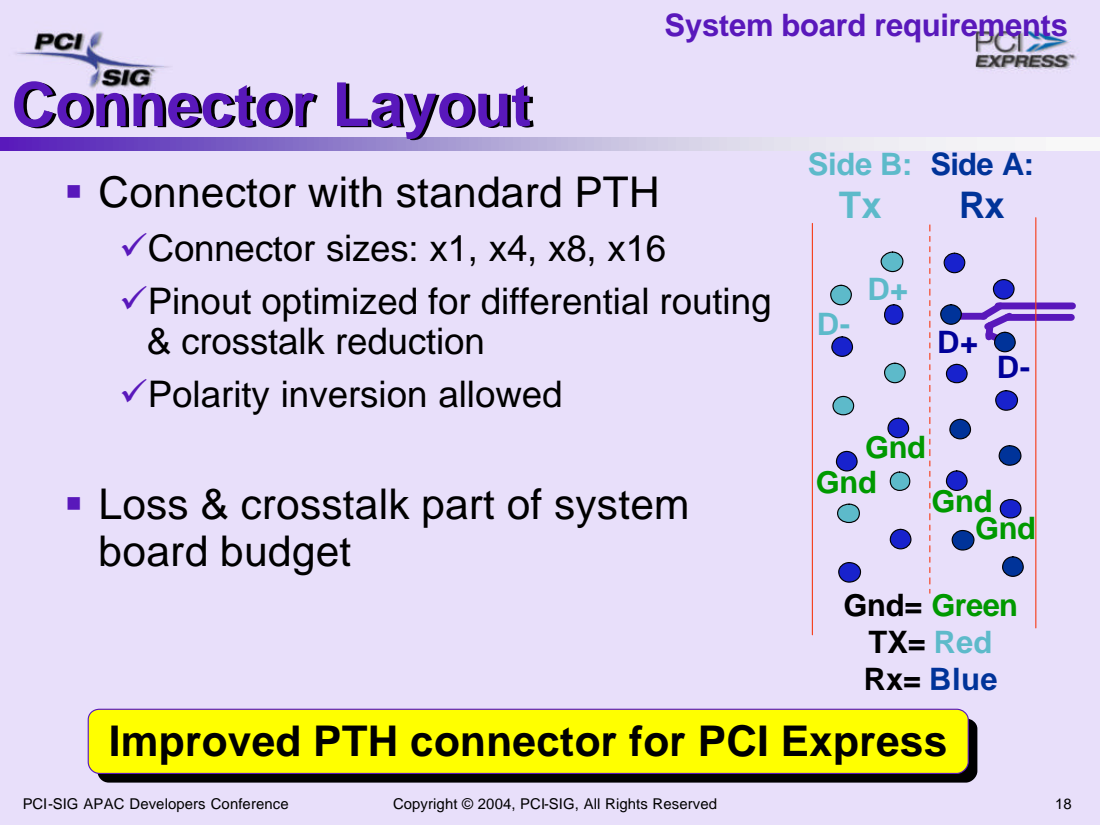
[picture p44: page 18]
PCI-SIG APAC Developers Conference; Copyright © 2004, PCI-SIG, All Rights Reserved; Side B: Tx; Side A: Rx; Gnd; Gnd= Green TX= Red Rx= Blue; Gnd Gnd

System board requirements

ß Connector with standard PTH
Çonnector sizes: x1, x4, x8, x16
¸Pinout optimized for differential routing
& crosstalk reduction
¸Polarity inversion allowed

ß Loss & crosstalk part of system
board budget

Improved PTH connector for PCI Express

PCI-SIG APAC Developers Conference | Copyright © 2004, PCI-SIG, All Rights Reserved | 19

## Power Rails

ß Increased current capability for x16 connector ¸Additional +12V pin; 1.1 Amp per pin capability
ß Helpful grouping of power supply pins Ȩases power delivery routing
ß ATX power supply connector
¸ 2x12 (recommended)
Power Rail | x16 Connector Spec
+3.3V Voltage Tolerance Current | ± 9% (max) 3.0 A (max)
+12V Voltage Tolerance Current | ± 8% (max) 5.5A (max)
+3.3Vaux Voltage Tolerance Current: Wake Non-Wake | ± 9% (max) 375 mA (max) 20 mA (max)

System board requirements

Update

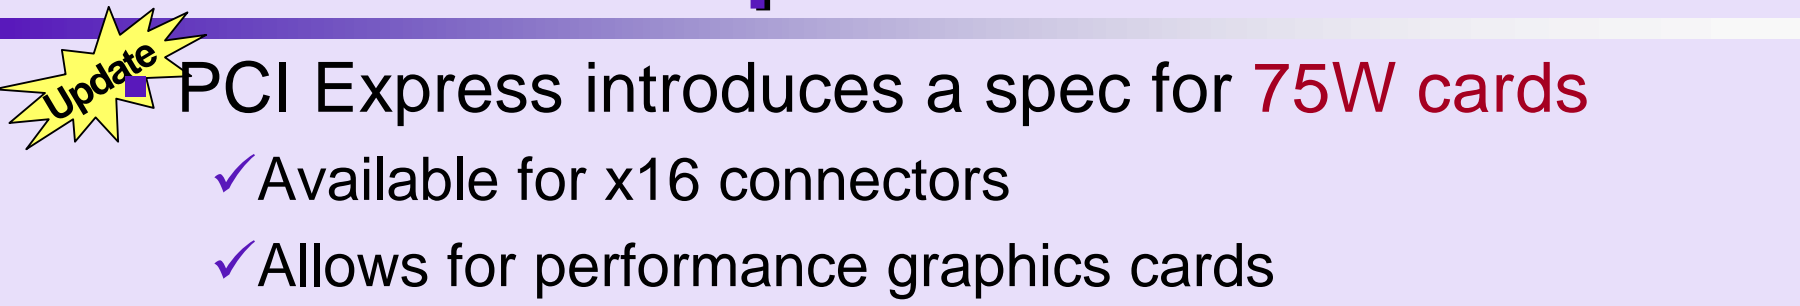
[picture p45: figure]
Update; ¸Available for x16 connectors ¸Allows for performance graphics cards

PCI-SIG APAC Developers Conference | Copyright © 2004, PCI-SIG, All Rights Reserved | 20

## Power Consumption

ß PCI Express introduces a spec for 75W cards

¸75W can be fully drawn thru x16 connector Ņote: ≤ 25W at initial power-up
(75W after configuration as a high power device) ß Up to 25W allowed for x1,x4,x8 cards

System board requirements

Connector Size ‡ Power Consumption Allowances
| X1 | x4/x8 | x16
Standard height | 10 W¹ (max) 25 W (max) | 25 W (max) | 25 W¹ (max) 75 W (max)
Low profile card | 10 W (max) | 10 W (max) | 25 W (max)
1. Max at initial power-up only.

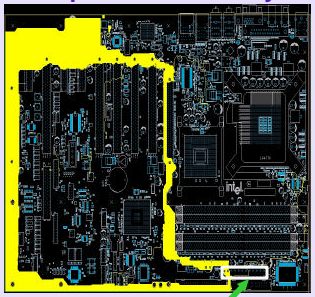
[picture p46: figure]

PCI-SIG APAC Developers Conference | Copyright © 2004, PCI-SIG, All Rights Reserved | 21

ß Ensure +3.3V & +12V tolerances at add-in card ß Max of 2%~3% MB +12V voltage drop (e.g. 360mV) Ţypical power supply = ± 5% drop
¸Balance trace width vs. length
Ȩxample: 100 mils min trace width,
= 12” length for +12V with 1oz Cu ß Proper power decoupling
¸Max current slew rate of 0.1A/μs Şuppress high freq coupling noise Ţune capacitor type/location
to board needs

## Power Delivery - 75W Support

System board requirements

Example uATX +12V layout

2x12 Power Supply Connector

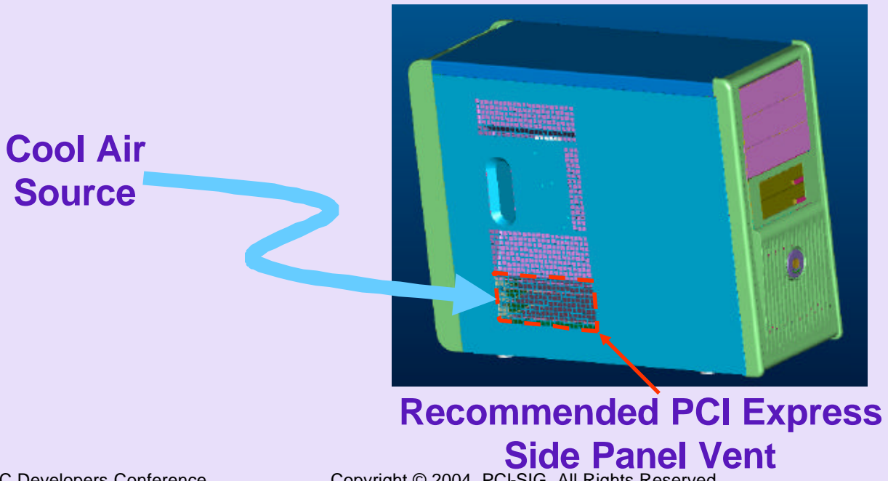
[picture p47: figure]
Recommended PCI Express Side Panel Vent; Cool Air Source

PCI-SIG APAC Developers Conference | Copyright © 2004, PCI-SIG, All Rights Reserved | 22

ß Platforms need to deliver cool air to x16 slot
¸Use side panel vents, ducting
¸75W card recommendation: ≤ 55oC air temp at graphics card fan intake
¸Use larger fans for better acoustics

## Thermal & Acoustic Management

System board requirements

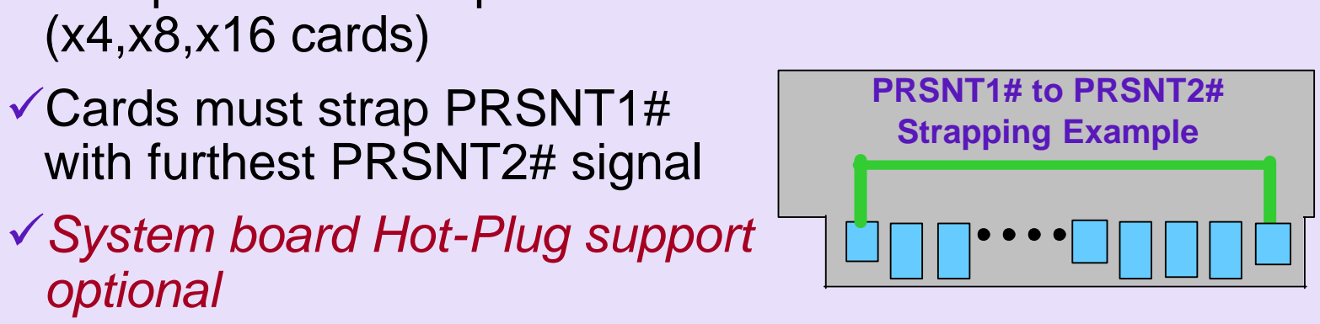
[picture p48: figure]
(x4,x8,x16 cards) Çards must strap PRSNT1# with furthest PRSNT2# signal Şystem board Hot-Plug support optional; PRSNT1# to PRSNT2# Strapping Example

PCI-SIG APAC Developers Conference | Copyright © 2004, PCI-SIG, All Rights Reserved | 23

## Card Edge Fingers

ß Remove ref plane under edge

Add-in card requirements

## Card Retention

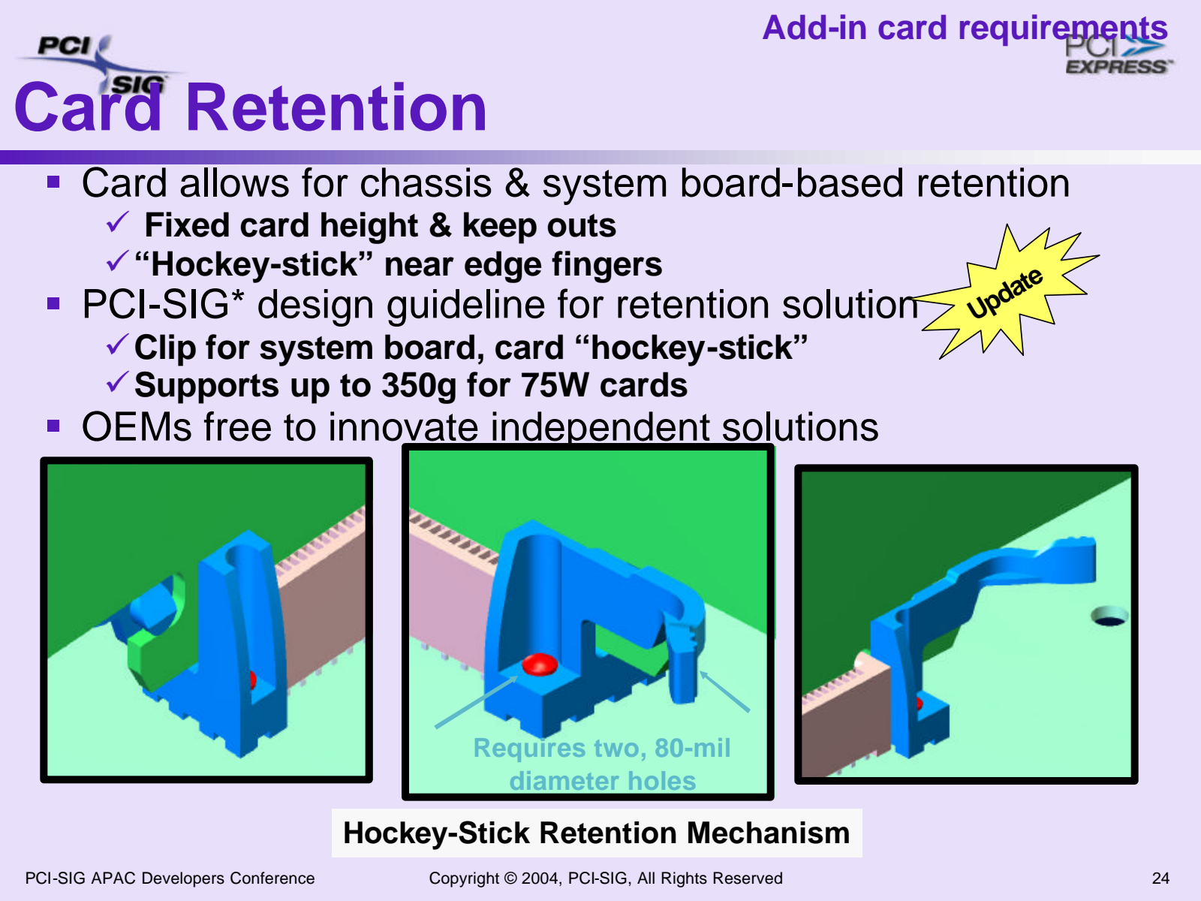
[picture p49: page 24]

PCI-SIG APAC Developers Conference | Copyright © 2004, PCI-SIG, All Rights Reserved | 24

ß Card allows for chassis & system board-based retention
¸ Fixed card height & keep outs
¸“Hockey-stick” near edge fingers
ß PCI-SIG* design guideline for retention solution
Çlip for system board, card “hockey-stick” Şupports up to 350g for 75W cards
ß OEMs free to innovate independent solutions

Update

Add-in card requirements

Hockey-Stick Retention Mechanism

Requires two, 80-mil
diameter holes

## Card Physical Dimensions

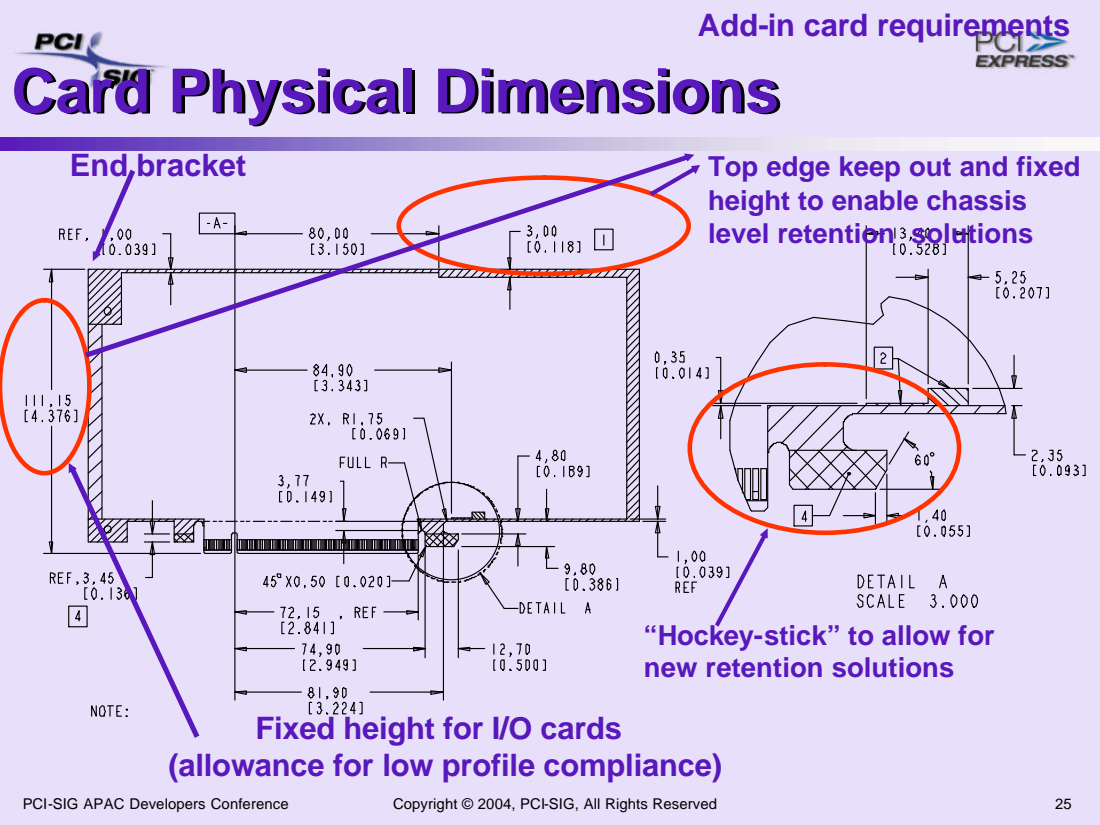
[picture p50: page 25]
PCI-SIG APAC Developers Conference; Copyright © 2004, PCI-SIG, All Rights Reserved; level retention; solutions; End bracket

Add-in card requirements

Top edge keep out and fixed
height to enable chassis

“Hockey-stick” to allow for
new retention solutions

Fixed height for I/O cards
(allowance for low profile compliance)

## Gfx Thermal & Acoustic

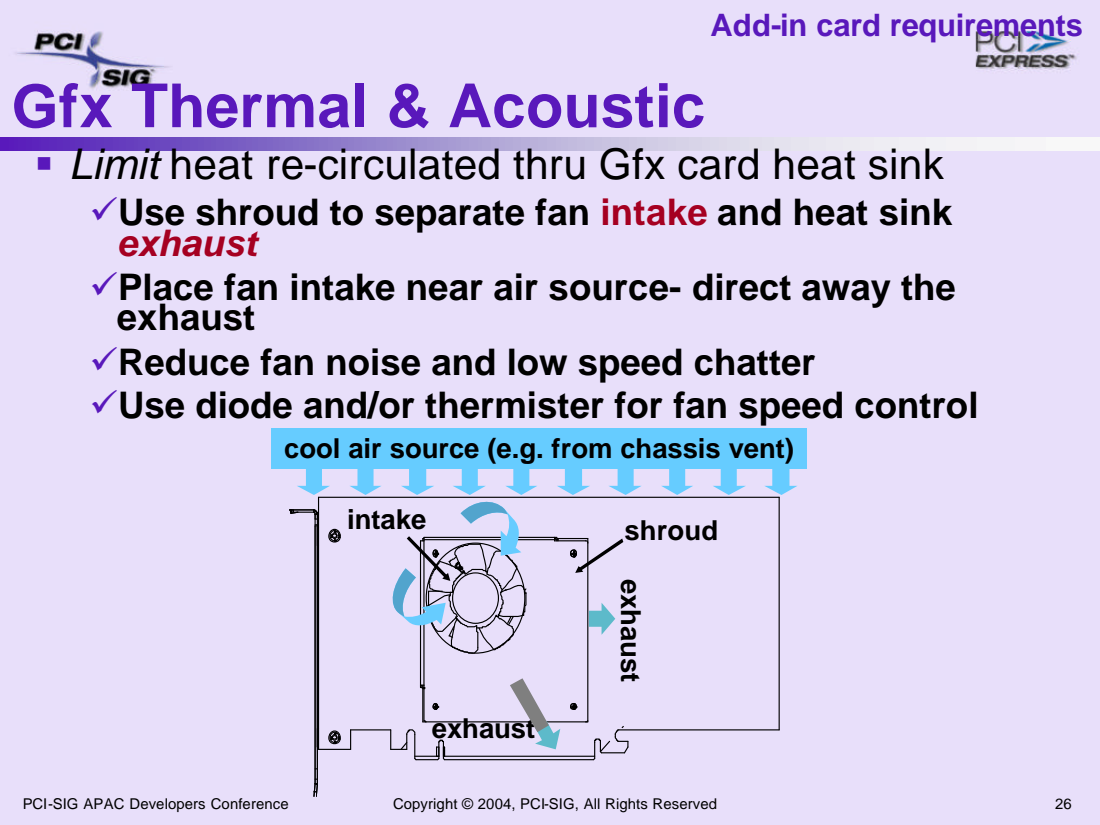
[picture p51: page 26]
PCI-SIG APAC Developers Conference; Copyright © 2004, PCI-SIG, All Rights Reserved; exhaust; intake; shroud

Add-in card requirements

ß Limit heat re-circulated thru Gfx card heat sink
¸Use shroud to separate fan intake and heat sink
exhaust
¸Place fan intake near air source- direct away the
Ŗeduce fan noise and low speed chatter
¸Use diode and/or thermister for fan speed control

cool air source (e.g. from chassis vent)

PCI-SIG APAC Developers Conference | Copyright © 2004, PCI-SIG, All Rights Reserved | 27

## Lab Signal Measurements

ß PCI Express devices generate compliance pattern per spec
ß Use compliance boards for signal validation
¸ Compliance Base Board (CBB) for add-in card measurements
¸ Compliance Load Board (CLB) for system board measurements
ß Measure eye diagrams with real time scope
¸ 6+ GHz analog bandwidth
¸ 20+ Gs sampling bandwidth
¸ Scope vendor should have eye diagram signal analysis SW tool

Signal validations

PCI Express connector

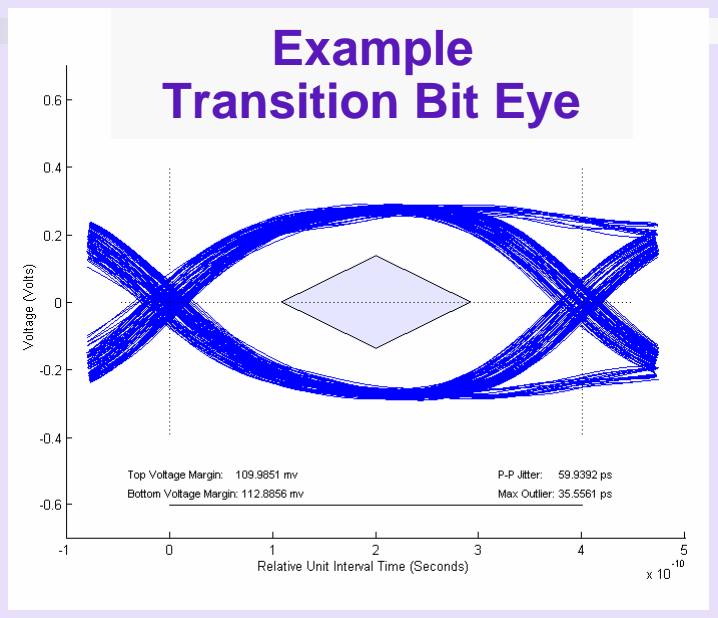
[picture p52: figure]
Example Transition Bit Eye
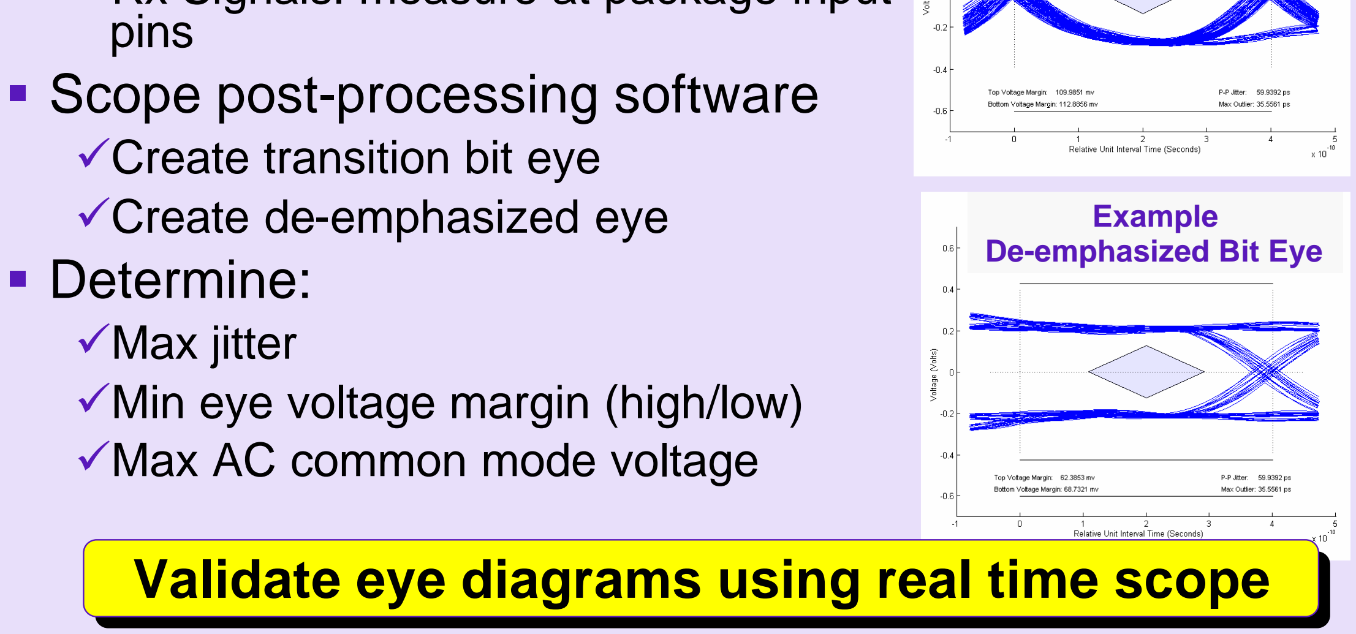
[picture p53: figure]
pins ß Scope post-processing software Çreate transition bit eye Çreate de-emphasized eye ß Determine: ¸Max jitter ¸Min eye voltage margin (high/low) ¸Max AC common mode voltage; Example De-emphasized Bit Eye

PCI-SIG APAC Developers Conference | Copyright © 2004, PCI-SIG, All Rights Reserved | 28

## Acquiring & Interpreting Results

ß Probe locations
Ţx Signals: measure at 50Ω loads
Ŗx Signals: measure at package input

Signal validations

Validate eye diagrams using real time scope

PCI-SIG APAC Developers Conference | Copyright © 2004, PCI-SIG, All Rights Reserved | 29

## Summary

ß PCI Express point-to-point layout is straightforward
ß Manage loss and jitter from PCB to meet interconnect budget
ß Follow basic layout rules and design tradeoffs to implement typical topologies
ß Improved connector & add-in card features -support for 75 Watt cards
ß Validate compliance eye diagrams using compliance boards and real time scope

Summary

PCI-SIG APAC Developers Conference | Copyright © 2004, PCI-SIG, All Rights Reserved | 30

## Collateral

ß For additional and updated information on PCI Express Architecture, visit
http://www.pcisig.com

PCI-SIG APAC Developers Conference | Copyright © 2004, PCI-SIG, All Rights Reserved | 31

## Thank you for attending the 2004 PCI-SIG Asia-Pacific

Developers Conference.

## For more information please go to www.pcisig.com

PCI-SIG APAC Developers Conference | Copyright © 2004, PCI-SIG, All Rights Reserved | 32

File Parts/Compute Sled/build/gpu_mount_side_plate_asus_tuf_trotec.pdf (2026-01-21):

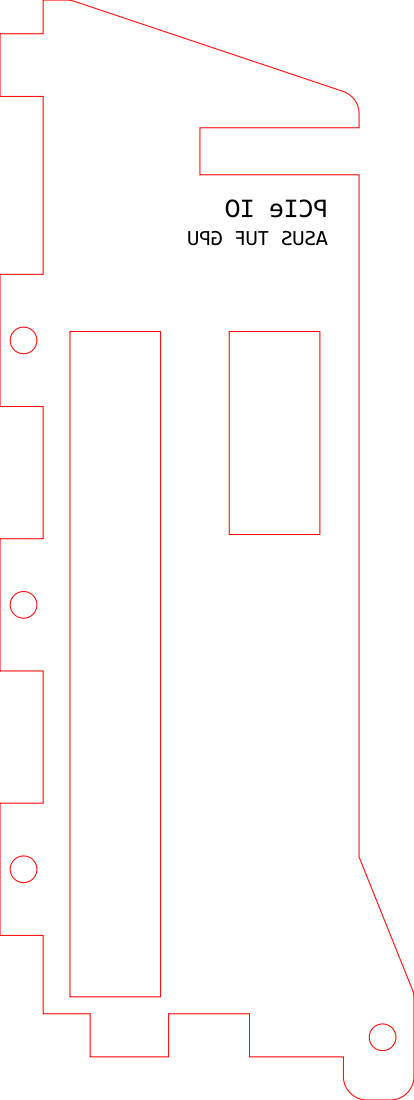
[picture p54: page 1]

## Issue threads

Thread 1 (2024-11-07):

Model number?

TheRealKingPin, 2024-11-07:
Hey Crozone! I may be jumping on a project like this soon. What model number of iMac did you start off with for your project? I read it was graphite slot loading, was it an m5521?  Also do you have a video of how it turned out?

crozone, 2024-11-16:
Hi there! Yes, it is a Graphite slot loading DV, M5521.

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

Currently the project is about 75% complete. The computer is functional, with a working internal display and power button. I've been using it as my primary PC for a few years now, and it works great. This has ironically hindered progress, since I'm reluctant to constantly tear it down to do the necessary upgrades...

Things that still need to be finished:

* Proper case fans with cooling ducts. Currently the computer cannot run without the rear iMac shell (the handle bit) in place due to airflow. I'm actively working on this.

* Front panel audio. I solved the power button switch and light with a single transistor, but getting the iMac audio jack detect to talk to Intel HD audio is a different beast. I understand the problem, but it's going to require a custom PCB.

* Side IO panel. This is half complete. I have all of the ports extended down and out onto a laser cut acrylic plate, but the plate isn't yet mounted to the machine.

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

* Re-doing the motherboard/GPU brackets. I'm unifying the motherboard + GPU + water pump into a single mounting solution (the "compute sled"). I'm designing it to be all laser cut acrylic. The idea is that the entire thing can be removed as a single piece by unscrewing a few bolts, which should make servicing a lot easier. Also redoing the cooling loop order, because my first go was crazy.

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

* Improving the radiator mounting solution. It's a simple fix but will need to fit around everything else, so I'm re-doing this last.

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

I'm still running a Ryzen 5900X and an RTX 3080. All up, the entire project has probably cost $4500 AUD so far, mostly from the standard PC parts and custom water loop components and fittings, as well as the riser cables and other bits and pieces.

If you do attempt one of these yourself, I'd love to see your approach and what can be improved. Especially let me know if you find a 15" 4:3 display that isn't hot garbage!

crozone, 2024-11-16:
Hi there! Yes, it is a Graphite slot loading DV, **M5521**.

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

Currently the project is about 75% complete. The computer is functional, with a working internal display and power button. I've been using it as my primary PC for a few years now, and it works great. This has ironically hindered progress, since I'm reluctant to constantly tear it down to do the necessary upgrades...

Things that still need to be finished:

* Proper case fans with cooling ducts. Currently the computer cannot run without the rear iMac shell (the handle bit) in place due to airflow. I'm actively working on this.

* Front panel audio. I solved the power button switch and light with a single transistor, but getting the iMac audio jack detect to talk to Intel HD audio is a different beast. I understand the problem, but it's going to require a custom PCB.

* Side IO panel. This is half complete. I have all of the ports extended down and out onto a laser cut acrylic plate, but the plate isn't yet mounted to the machine.

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

* Re-doing the motherboard/GPU brackets. I'm unifying the motherboard + GPU + water pump into a single mounting solution (the "compute sled"). I'm designing it to be all laser cut acrylic. The idea is that the entire thing can be removed as a single piece by unscrewing a few bolts, which should make servicing a lot easier. Also redoing the cooling loop order, because my first go was crazy.

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

* Improving the radiator mounting solution. It's a simple fix but will need to fit around everything else, so I'm re-doing this last.

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

I'm still running a Ryzen 5900X and an RTX 3080. All up, the entire project has probably cost $4500 AUD so far, mostly from the standard PC parts and custom water loop components and fittings, as well as the riser cables and other bits and pieces.

If you do attempt one of these yourself, I'd love to see your approach and what can be improved. Especially let me know if you find a 15" 4:3 display that isn't hot garbage!

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

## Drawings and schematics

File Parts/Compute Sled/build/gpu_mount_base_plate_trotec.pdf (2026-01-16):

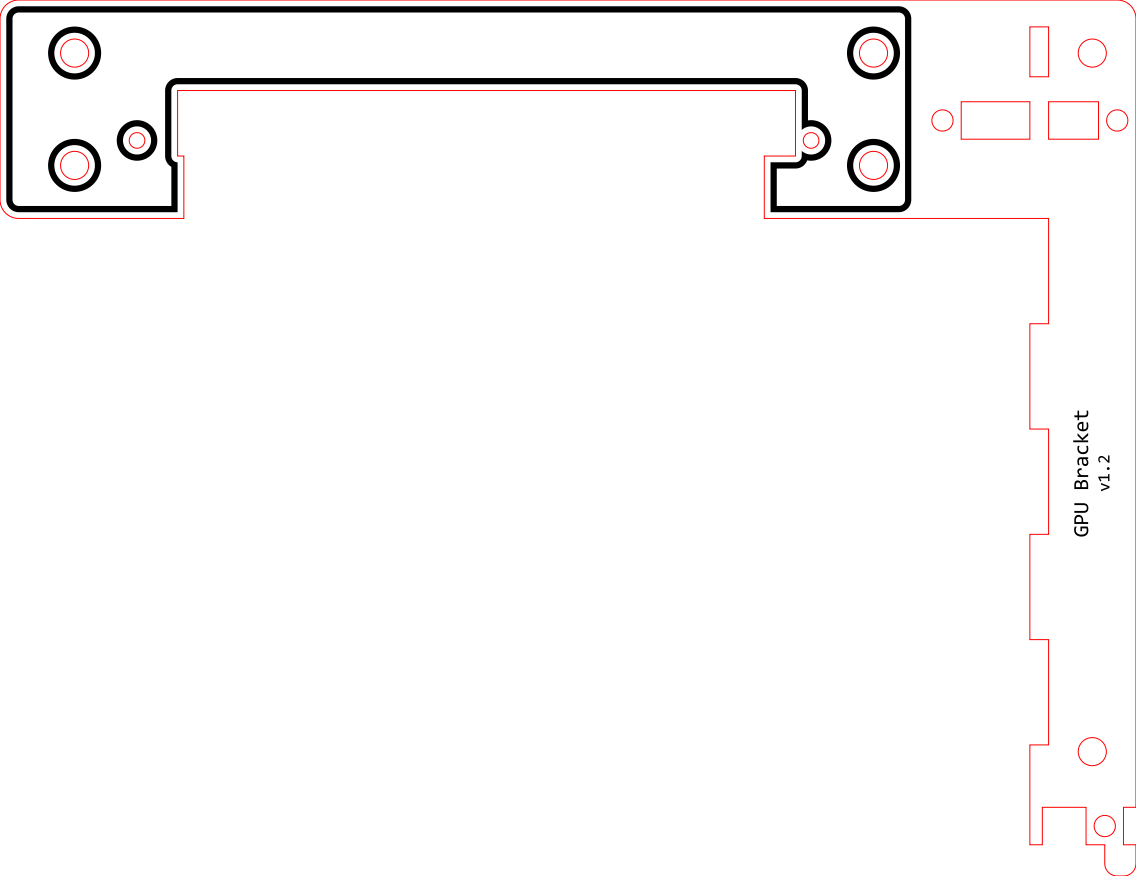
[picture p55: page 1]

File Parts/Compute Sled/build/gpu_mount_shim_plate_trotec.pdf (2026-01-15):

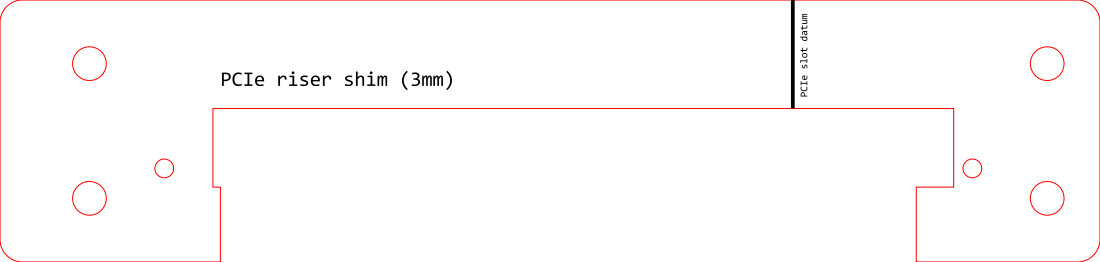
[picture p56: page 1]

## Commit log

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2024-05-24 Created bottom left mount v4. Mounting holes are marginally closer together.
    Refactored the scad file to reduce global variables, and nested some modules.
    Added baseplate, moving baseplate posts out of the bottom left bracket module and into the baseplate module.
    Added display module, which represents the LCD panel at the front of the computer.
    [design.scad, mobo_bottom_left_mount_v4.stl]
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2024-05-24 Factored out some of the modules from design.scad into shared library scad
    [design.scad]
2024-05-24 Update ridge angles in display mount prototype.
    Add display mount prototype v2
    [display_mount_proto.scad, display_mount_proto_2.stl]
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2024-05-24 Create display mount prototype v6.
    This change adds a cutout for the clear plastic bracket that attaches to the display frame
    [display_mount_proto.scad, display_mount_proto_6.stl]
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2024-05-24 Updated round cube module to gracefully switch into normal cube mode when radius is zero or less
    [shared.scad]
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2024-05-24 Add display assembly design, with first iteration of top left and top right display brackets (v1)
    [display_mount_assembly.scad, display_mount_tl_1.stl, display_mount_tr_1.stl]
2024-05-24 Fix semicolon
    [design.scad]
2024-05-24 Rename display mount proto to display mount top
    [display_mount_assembly.scad, display_mount_top.scad]
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2024-05-24 Fix display keepout height
    [display_mount_assembly.scad]
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2024-05-24 Fixed naming convention for left/right within design
    [design.scad]
2024-05-24 Added display control mount for display controller buttons
    [display_control_mount.scad, display_control_mount_1.stl]
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2024-05-24 WIP.
    Started re-organisation of mounting brackets.
    Added radiator mounting bracket (prototype WIP)
    Added PSU mounting bracket (WIP)
    [2Dshapes.scad, PCIeSpacer.scad, PCIeSpacer.stl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]
2024-05-24 PSU tub nearly complete.
    Update material thickness with measured value
    Fix and improve tab strip module
    [psu_mount_2D.scad, shared_settings.scad, tab_strip.scad]
2024-05-24 Add screw-holes for mounting PSU tub to base plate
    Refine side holder edge plates size and shape
    [psu_mount_2D.scad]
2024-05-24 Change material thickness to 4.5mm
    Correct tab height vs material thickness
    Remove additional screw holes not present in stock baseplate
    Fix text location
    Increase tolerance around PSU
    [psu_mount_2D.scad]
2024-05-24 Improve PSU mount, v1.2
    Add radiator mount bottom bracket
    Update combined model
    [baseplate_screw_holes.scad, bottom_connecting_tab_2d.scad, bottom_mount_settings.scad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]
2024-05-24 Reconfigure radiator mount and swap port sides
    [motherboard_fixture_3d.scad, rad_bottom_mount_2D.scad, rad_mount_2D.scad]
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2024-05-24 Adjust circular segments when rendering and tweak label position
    [display_converter_mount_2D.scad]
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2024-05-24 Update Pump Mount to v1.1
    Tweak pump mount parameters
    [pump_mount_2d.scad]
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2024-05-24 Version 1.2
    Move PCB and fan downwards to clear display
    Add EXPORT_RENDER_MODE parameter
    [display_converter_mount_2D.scad]
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2025-12-29 Update compute sled (WIP!) and add relevant documentation
    [compute_sled.scad]
2025-12-29 [WIP] Added GPU mount
    Added reference outline for PCIe card and riser
    [gpu_mount.scad]
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2025-12-29 Fix error in tab strip module
    [tab_strip.scad]
2025-12-29 Tweak plastic support cutout to make room for PCIe cable wrapping around at top
    [gpu_mount.scad]
2025-12-29 Add base of PCIe mounting bracket and color code sections
    [gpu_mount.scad]
2025-12-29 Extend bracket to include GPU mounting
    Add mounting holes for mounting to motherboard plate
    [gpu_mount.scad]
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2025-12-29 Tweak bracket plate size and fix alignment
    [gpu_mount.scad]
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2026-01-04 Add screw mount and tab slot mount to GPU bracket
    Add reference PCIe brackets
    [gpu_mount.scad]
2026-01-05 Add crossplate
    Render clearance for screwdriver access to mounting screws
    Add metric screw hole sizes as constants
    [gpu_mount.scad]
2026-01-10 Factor out screw hole sizes into import
    Add functions for getting pcie offset and mounting hole coordinates
    [gpu_mount.scad]
2026-01-10 Add GPU mount
    Move motherboard mounting hole coordinates into variable
    Add PCIe slot to motherboard
    General refactors
    [compute_sled.scad]
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2026-01-10 Change to a side plate instead of a cross plate [WIP]
    Make side plate material thickness thinner than standard material thickness
    Tweak sizes and mounting hole positions
    [gpu_mount.scad]
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2026-01-14 Add shim to GPU mount to raise PCIe card and clear base plate
    Complete side plate, with tabs
    Add engraving to base plate
    [gpu_mount.scad]
2026-01-15 Changes for GPU mount v1.1 based on testing with initial build
    [gpu_mount.scad]
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2026-01-15 Fix side plate
    [gpu_mount.scad]
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2026-01-16 Add screwhole from side plate into screw plate
    [gpu_mount.scad]
2026-01-16 Fix screw plate tabs
    [gpu_mount.scad]
2026-01-16 Remove mounting hole causing weak spot in base plate
    [gpu_mount.scad]
2026-01-16 Use M3 screws for fastening bracket together, instead of M2
    [gpu_mount.scad]
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2026-01-19 Tweak PCIe IO side plate to better fit GPU
    Engrave the version of the IO side plate
    [gpu_mount.scad]
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2026-03-31 Begin work on disc drive mounting solution
    Add reference model for Pioneer BDR-XS07B-UHD external slot loading blu-ray drive
    [pioneer_bdr-xs07b-uhd.scad, pioneer_drive_mount.scad]
2026-04-01 Fix slot position
    [pioneer_bdr-xs07b-uhd.scad]
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2026-06-02 Share common variables between GPU mount and compute sled
    [shared_values.scad]
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2026-06-05 Increase screw head clearance
    [gpu_mount.scad]
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2026-06-05 Move lower right mounting wing and add hole for GPU power cable
    Tweak PCIe cutout size
    Tweak mount hole positions
    [compute_sled.scad]
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2026-06-05 Change motherboard standoff screw hole clearance
    [screw_hole_sizes.scad]
2026-06-05 Fix render and export modes
    [compute_sled.scad]
2026-06-05 Change pump mount holes to M3 drill instead of M3 clearance so it can be tapped for direct mounting
    [compute_sled.scad]
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2026-06-07 Add GPU support block for RTX 3080 TUF with EK Vector waterblock
    [compute_sled.scad]
2026-06-07 Change motherboard mounting screw holes to M3 drill holes for tapping, to allow M3 male-female standoffs to be screwed in directly
    [compute_sled.scad]
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2026-06-07 Remove cutouts for motherboard mounting screws since threaded standoffs are being used now
    [gpu_mount.scad]
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2026-06-08 Correct GPU support block
    [compute_sled.scad]
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2026-06-10 Fix position of lowre mounting holes
    [compute_sled.scad]
